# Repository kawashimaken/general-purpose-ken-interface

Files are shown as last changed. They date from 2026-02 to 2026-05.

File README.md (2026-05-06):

# KEN Interface

A modular, multi-MCU prototyping platform with a unified pin-assignment standard and horizontally-stackable expansion boards.

> **Status**: Hardware design (KiCad) is published in this repository. Software libraries (Hardware Abstraction Layer and demo applications) are **under active development** and will be released separately in the near future.

---

## 📺 Watch the Introduction

KEN Interface — The AI Voice Chatbot You Can Build with ESP32-S3 (https://www.youtube.com/watch?v=sNuc83q-v-A)

KEN Interface — Stop Stacking Your Dev Boards — There's a Better Way (https://www.youtube.com/watch?v=DMRa_tTHA18)

---

## What is KEN Interface?

At its core, **KEN Interface is a standardized pin-assignment pattern shared between MCU boards and expansion boards.**

If you have worked with Arduino shields, the idea will feel familiar — because the pin layout is fixed, any compatible expansion board just plugs straight in and works. KEN Interface follows the same philosophy, but with a few key differences.

### Three Distinctive Features

#### 1. Horizontal Expansion

Instead of stacking boards vertically like Arduino shields, KEN Interface uses **15×2 right-angle pin headers** so boards connect **side by side**. The left and right connectors are completely symmetrical — it does not matter which side you plug into.

Add a **junction board** into the mix, and you can expand in multiple directions: left, right, up, down. Since nothing is buried under another board, every module stays visible, and you can read the pin labels right off the PCB. No more hunting for which wire goes where.

#### 2. Multi-MCU Support

KEN Interface currently supports **four MCUs**:

| MCU | Notes |
|---|---|
| **ESP32** (WROOM-32) | Wi-Fi / BLE built-in |
| **ESP32-S3** (WROOM-1) | Wi-Fi / BLE / native USB / dual core |
| **Raspberry Pi Pico** (RP2040) | Dual core, PIO for I2S, low cost |
| **STM32G431** (WeAct CBU6) | 170 MHz, real DSP, hardware FPU |

The same expansion board works with all of them. **Swap the MCU board, and you are good to go — no rewiring required.**

#### 3. Software Portability

Even though each MCU uses different physical pin numbers, the **functional pin groups sit at fixed positions** across all KEN Interface boards. Build your code around a HAL (Hardware Abstraction Layer), and a single codebase can run on all four MCUs.

> The Ken Interface software library that provides this HAL is currently being developed and will be released in a separate repository.

---

## Pin Assignment Design

The pin layout exposes the default peripheral interfaces that most modern MCUs provide out of the box.

### Functional Pin Groups

| Group | Purpose |
|---|---|
| **UART_A** | General-purpose serial communication |
| **UART_B** | Secondary serial / debugging (some MCUs have native USB instead) |
| **I2C** | Sensors, OLEDs, character LCDs, I/O expanders |
| **SPI** | TFT displays, fast peripherals |
| **I2S_A / I2S_B** | Microphones, digital audio (PIO emulation on Pico) |
| **PWM_A — PWM_F** | DC motors, stepper motors, BLDC motors, servos |
| **ADC_A / ADC_B** | Analog inputs (sensors, joysticks) |
| **Power rails** | 3.3 V and 5 V |

### Design Principle

> *"If the MCU supports it, we connect it. If it does not, it is just **Not Available**."*

Not every MCU covers every group. For example:
- ESP32 (WROOM-32) does not expose UART_B (limited free GPIO).
- STM32G431 shares some SPI and PWM pins due to peripheral multiplexing constraints.

These were deliberate trade-offs, figured out the hard way through multiple board revisions.

### Detailed Pin Mapping

The complete pin assignment matrix across all four MCUs is documented in the KiCad schematic and accompanying spreadsheet (see [`kicad/`](./kicad/)).

---

## What Is in This Repository

```
.
├── kicad/              KiCad PCB project — schematic, board, and gerbers
├── LICENSE             MIT License
└── README.md           This file
```

Currently this repository contains the **hardware design only** (KiCad project for the KEN Interface base board and expansion modules).

The accompanying software (HAL library and example applications) is under active development and will be linked here once published.

---

## Hardware

### Connector Specification

- **Side connectors**: 15×2 right-angle pin headers, 2.54 mm pitch
- **Symmetric pinout**: left and right sides are mirror images, so any expansion board can attach to either side
- **Power**: 3.3 V and 5 V rails routed through every connector

### Expansion Boards (existing designs)

Several expansion modules built on KEN Interface:

- **SPI TFT display board** (ILI9341, 2.4-inch)
- **I2S microphone + audio amplifier board**
- **MCP23008 I/O expander + analog joystick board**
- **BLDC motor driver board** (3-PWM, for SmartKnob / SimpleFOC)
- **Junction board** (4-direction expansion)

---

## Challenges and Limitations

KEN Interface is not a silver bullet. A few honest caveats:

- **Manufacturing cost.** Symmetric routing tends to push designs toward 4-layer PCBs, making mistakes expensive.
- **Board footprint.** Horizontal expansion uses desk space. KEN Interface is designed for **prototyping and experimentation**, not for final compact products. Once a design is validated, the natural next step is to consolidate everything onto a single custom PCB.
- **Software portability has limits.** A few examples:
  - LovyanGFX does not support STM32G4.
  - STM32G431 often requires SoftWire instead of hardware I2C in this pin layout.
  - Dual-core parallelism is specific to ESP32 / ESP32-S3.
  - I2S microphone support on STM32G431 lacks a ready-made Arduino library.

A well-designed HAL can hide many of these differences, but it cannot eliminate them entirely. KEN Interface provides a common hardware standard and a foundation for HAL design — it does not remove the underlying differences between MCUs.

- **Not for every use case.** Highly specialized projects (large multi-display setups, tightly integrated mechanical builds) may still need fully custom PCBs.

---

## Roadmap

Planned additions include:

- LoRa expansion board
- CAN bus expansion board
- Ethernet expansion board
- Additional sensor modules
- Support for more MCUs
- Dedicated power supply board
- Software HAL library and reference applications (separate repository, coming soon)

---

## Build Your Own

The KiCad project template is published in this repository. If you would like to build your own KEN Interface-compatible board, the schematic symbols, footprints, and design rules are all in [`kicad/`](./kicad/).

Pull requests, design suggestions, and new expansion-board ideas are very welcome.

---

## License

The hardware design files in this repository are released under the **MIT License** (see [LICENSE](./LICENSE)).

Future software components will be released under their own licenses — typically MIT or LGPL — and will be linked from this README once published.

---

## Author

Designed and maintained by **Kawashima Ken** ([@kawashimaken](https://github.com/kawashimaken)).

If you build something with KEN Interface, please consider sharing it — issues, pull requests, and ideas are all welcome.

---

## Acknowledgments

- KEN Interface stands on the shoulders of the wider open-source hardware community: KiCad, Arduino, ESP-IDF, Earle Philhower's Arduino-Pico core, Arduino_Core_STM32, and many display / sensor library authors whose work makes prototyping like this possible.

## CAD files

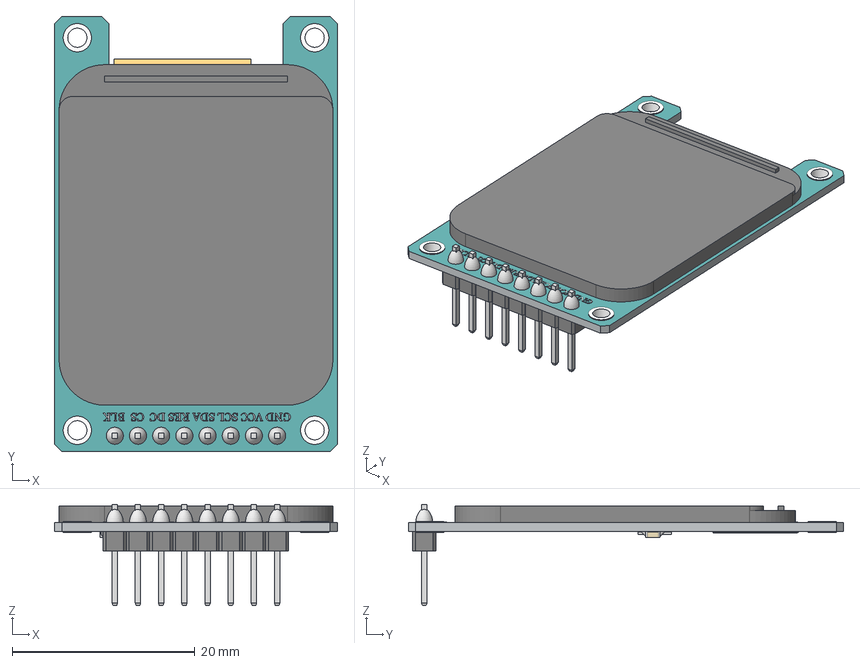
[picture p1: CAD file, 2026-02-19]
kicad/display-with-ken-interface-2/3d_models/Display 1.69 ST7789V2.stp
31.0 x 47.7 x 11.1 mm
PCB
Display
Pin x 8
R-0603 x 3
C-0603 x 2
U-0603

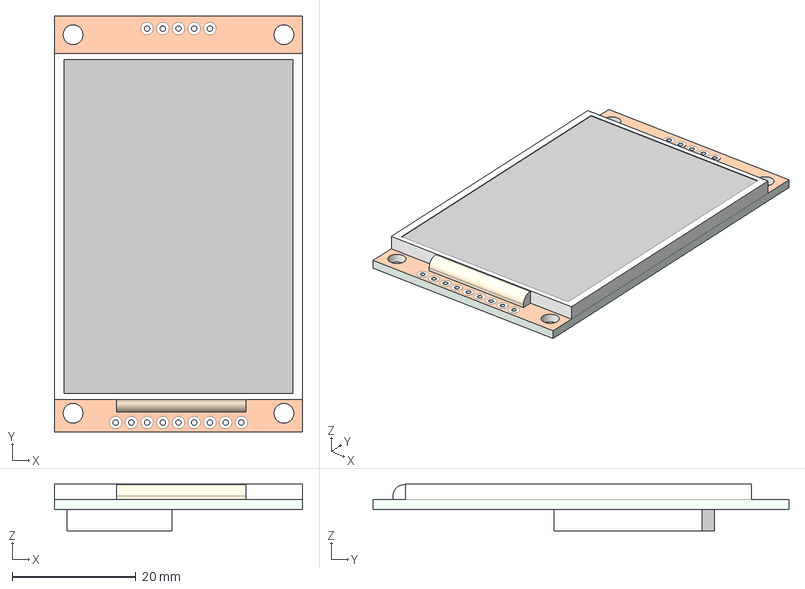
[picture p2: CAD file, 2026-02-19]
kicad/display-with-ken-interface-2/3d_models/2.2 inch tft display .step
40.1 x 67.2 x 7.57 mm

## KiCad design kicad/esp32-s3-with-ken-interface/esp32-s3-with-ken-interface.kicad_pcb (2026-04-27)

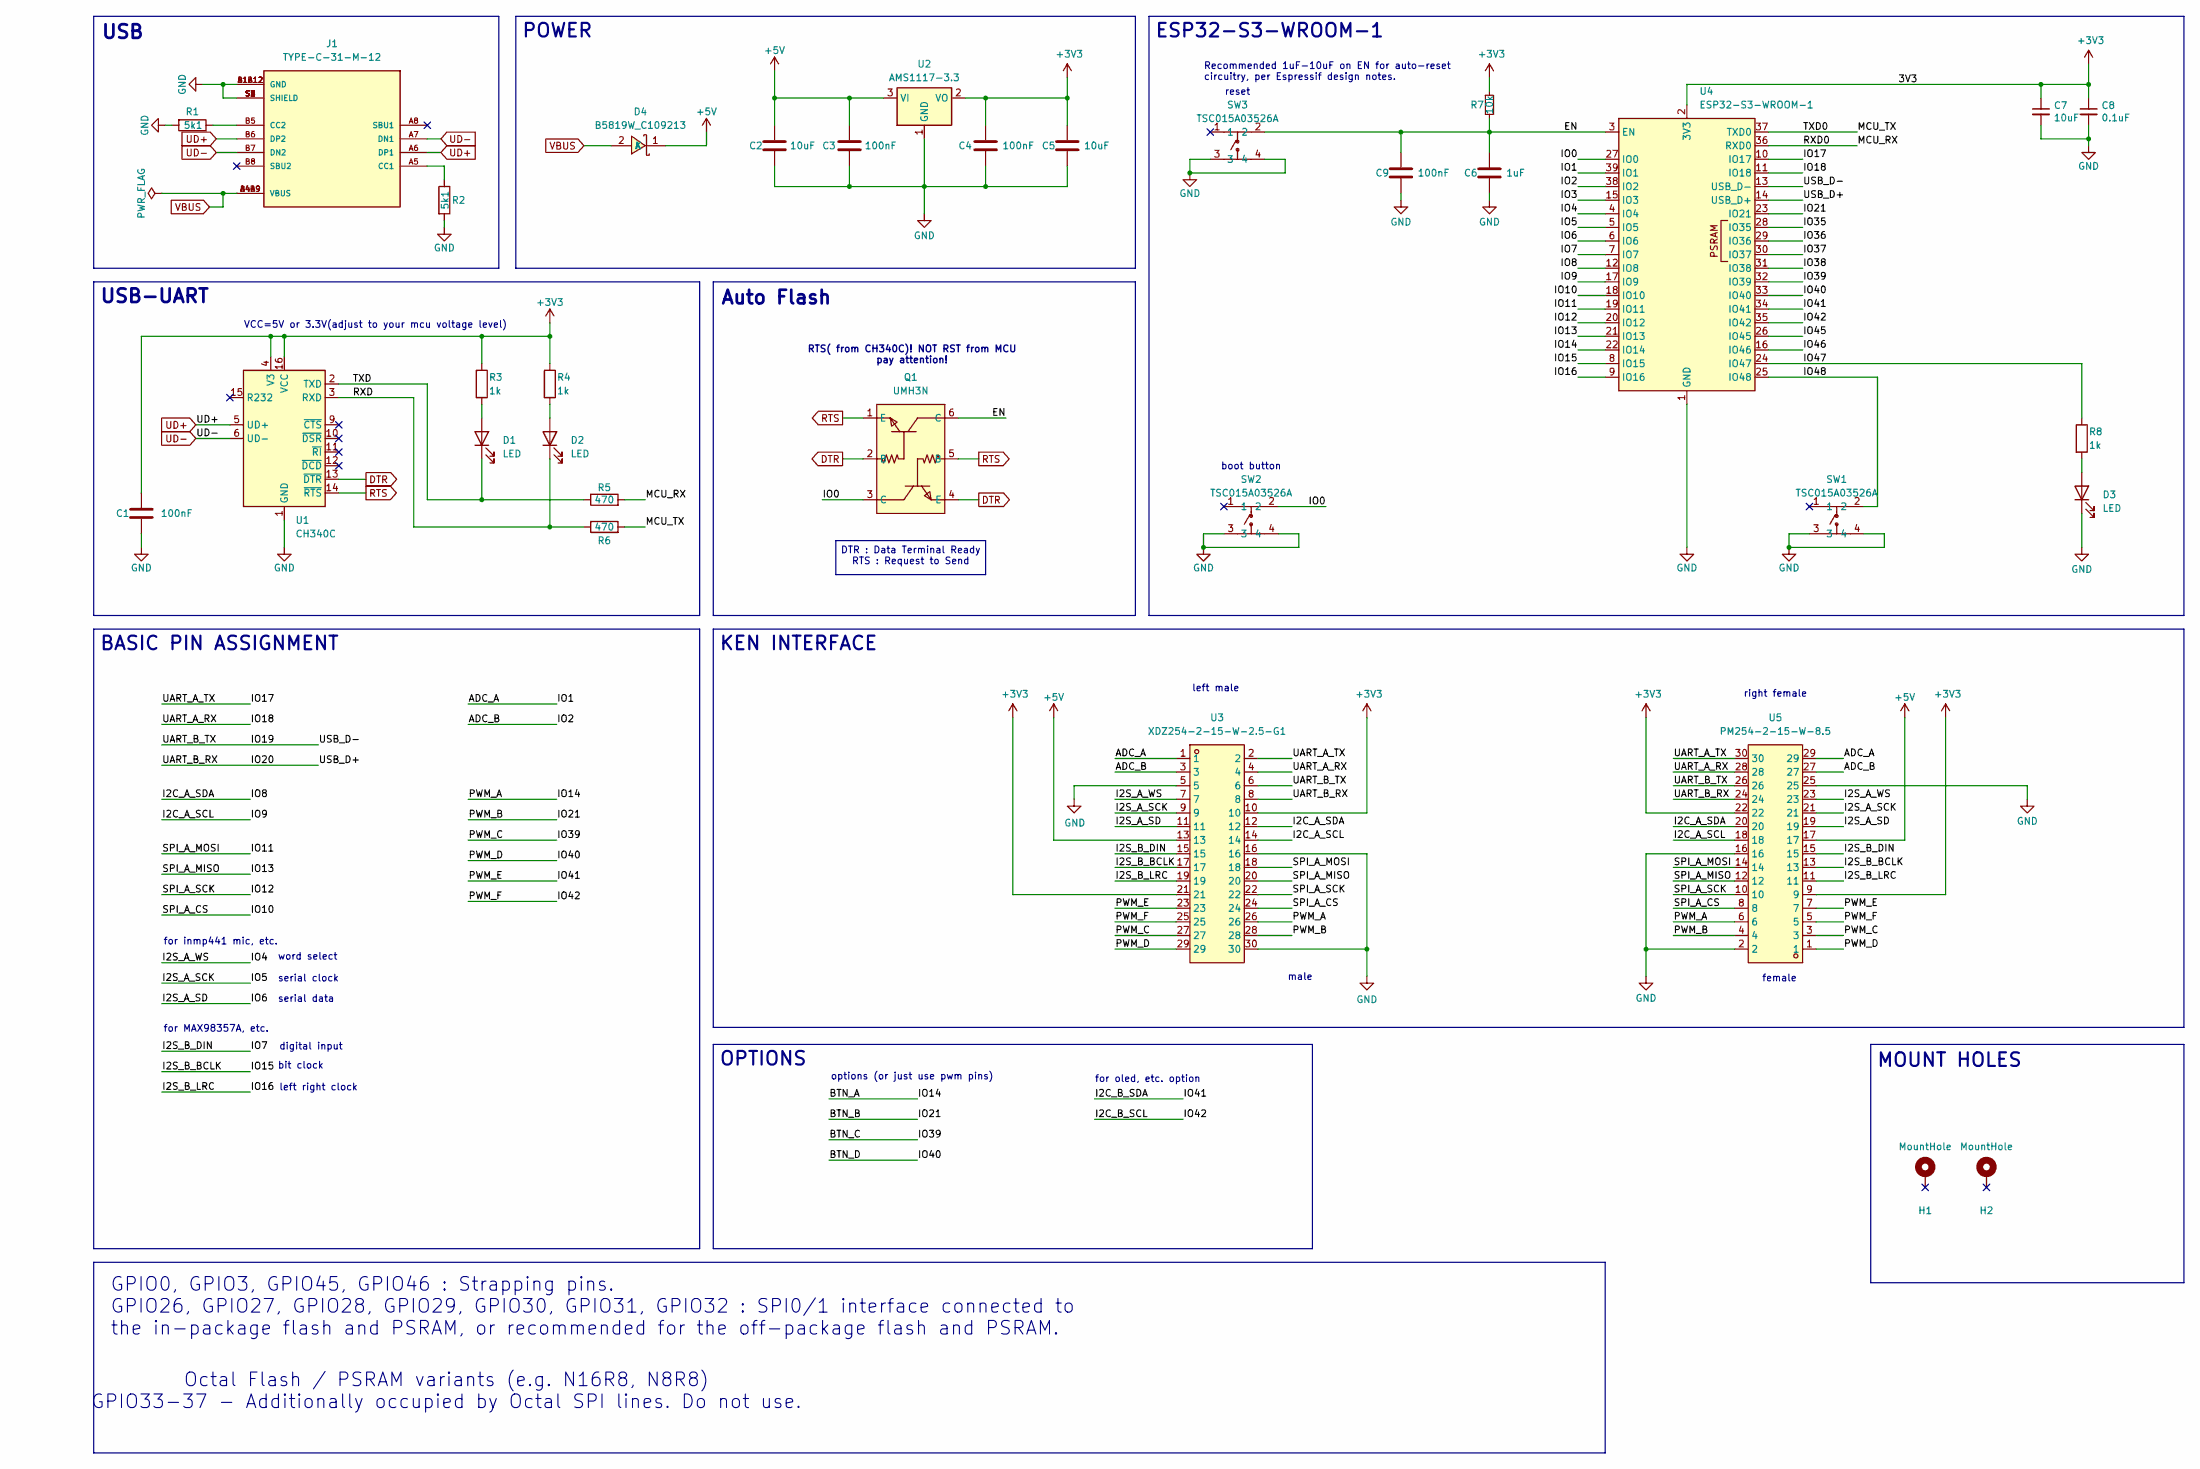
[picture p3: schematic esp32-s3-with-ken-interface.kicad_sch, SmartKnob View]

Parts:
C1, C3, C4, C9: 100nF; C_0603_1608Metric_Pad1.08x0.95mm_HandSolder
C2, C5: 10uF; C_1206_3216Metric_Pad1.33x1.80mm_HandSolder
C6: 1uF; C_0603_1608Metric_Pad1.08x0.95mm_HandSolder
C7: 10uF; C_0805_2012Metric_Pad1.18x1.45mm_HandSolder; LCSC C15850
C8: 0.1uF; C_0603_1608Metric_Pad1.08x0.95mm_HandSolder; LCSC C1591
D1, D2, D3: LED; LED_1206_3216Metric_Pad1.42x1.75mm_HandSolder
D4: B5819W_C109213; SOD-123_L2.8-W1.8-LS3.7-RD; LCSC Part C109213
H1, H2: MountHole; MountingHole_3.2mm_M3_DIN965_Pad; LCSC C2911210 or C2911532 (screw), C2961595 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
J1: TYPE-C-31-M-12; HRO_TYPE-C-31-M-12; PARTREV A
Q1: UMH3N; SC-70-6_L2.2-W1.3-P0.65-LS2.1-BR; LCSC Part C62892
R1, R2: 5k1; R_0603_1608Metric_Pad0.98x0.95mm_HandSolder
R3, R4, R8: 1k; R_0603_1608Metric_Pad0.98x0.95mm_HandSolder
R5, R6: 470; R_0603_1608Metric_Pad0.98x0.95mm_HandSolder
R7: 10k; R_0603_1608Metric_Pad0.98x0.95mm_HandSolder; LCSC C98220
SW1, SW2, SW3: TSC015A03526A; SW-SMD_4P-L4.5-W4.5-P3.00-LS6.8; LCSC Part C2888900
U1: CH340C; SOIC-16_3.9x9.9mm_P1.27mm
U2: AMS1117-3.3; SOT-223-3_TabPin2
U3: XDZ254-2-15-W-2.5-G1; HDR-TH_30P-P2.54-H-M-R2-C15-S2.54-N; LCSC Part C18905913
U4: ESP32-S3-WROOM-1
U5: PM254-2-15-W-8.5; HDR-TH_30P-P2.54-H-F-R2-C15-W8.5; LCSC Part C2897435

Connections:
+3V3: C1.1, C4.1, C5.1, C7.1, C8.1, R3.1, R4.1, R7.1, U1.4 (V3), U1.16 (VCC), U2.2 (VO), U3.10, U3.21, U4.2 (3V3), U5.9, U5.22
+5V: C2.1, C3.1, D4.1 (K), U2.3 (VI), U3.13, U5.17
/ADC_A: U3.1, U4.39 (IO1), U5.29
/ADC_B: U3.3, U4.38 (IO2), U5.27
/BTN_A: U3.26, U4.22 (IO14), U5.6
/BTN_B: U3.28, U4.23 (IO21), U5.4
/BTN_C: U3.27, U4.32 (IO39), U5.3
/BTN_D: U3.29, U4.33 (IO40), U5.1
/EN: C6.1, C9.1, Q1.6 (C), R7.2, SW3.2, U4.3 (EN)
/I2C_A_SCL: U3.14, U4.17 (IO9), U5.18
/I2C_A_SDA: U3.12, U4.12 (IO8), U5.20
/I2C_B_SCL: U3.25, U4.35 (IO42), U5.5
/I2C_B_SDA: U3.23, U4.34 (IO41), U5.7
/I2S_A_SCK: U3.9, U4.5 (IO5), U5.21
/I2S_A_SD: U3.11, U4.6 (IO6), U5.19
/I2S_A_WS: U3.7, U4.4 (IO4), U5.23
/I2S_B_BCLK: U3.17, U4.8 (IO15), U5.13
/I2S_B_DIN: U3.15, U4.7 (IO7), U5.15
/I2S_B_LRC: U3.19, U4.9 (IO16), U5.11
/IO0: Q1.3 (C), SW2.2, U4.27 (IO0)
/IO3: U4.15 (IO3)
/IO10: U3.24, U4.18 (IO10), U5.8
/IO11: U3.18, U4.19 (IO11), U5.14
/IO12: U3.22, U4.20 (IO12), U5.10
/IO13: U3.20, U4.21 (IO13), U5.12
/IO17: U3.2, U4.10 (IO17), U5.30
/IO18: U3.4, U4.11 (IO18), U5.28
/IO19: U3.6, U4.13 (USB_D-), U5.26
/IO20: U3.8, U4.14 (USB_D+), U5.24
/IO35: U4.28 (IO35)
/IO36: U4.29 (IO36)
/IO37: U4.30 (IO37)
/IO38: U4.31 (IO38)
/IO45: U4.26 (IO45)
/IO46: U4.16 (IO46)
/IO47: R8.1, U4.24 (IO47)
/IO48: SW1.2, U4.25 (IO48)
/MCU_RX: R5.2, U4.36 (RXD0)
/MCU_TX: R6.2, U4.37 (TXD0)
/RXD: D2.1 (K), R6.1, U1.3 (RXD)
/TXD: D1.1 (K), R5.1, U1.2 (TXD)
DTR: Q1.2 (B), Q1.4 (E), U1.13 (~DTR)
GND: C1.2, C2.2, C3.2, C4.2, C5.2, C6.2, C7.2, C8.2, C9.2, D3.1 (K), J1.A1B12 (GND), J1.B1A12 (GND), J1.S1 (SHIELD), J1.S2 (SHIELD), J1.S3 (SHIELD), J1.S4 (SHIELD), R1.2, R2.2, SW1.3, SW1.4, SW2.3, SW2.4, SW3.3, SW3.4, U1.1 (GND), U2.1 (GND), U3.5, U3.16, U3.30, U4.1 (GND), U4.40 (GND), U4.41 (GND), U5.2, U5.16, U5.25
unnamed: D1.2 (A), R3.2
unnamed: D2.2 (A), R4.2
unnamed: D3.2 (A), R8.2
unnamed: J1.A5 (CC1), R2.1
unnamed: J1.B5 (CC2), R1.1
RTS: Q1.1 (E), Q1.5 (B), U1.14 (~RTS)
UD+: J1.A6 (DP1), J1.B6 (DP2), U1.5 (UD+)
UD-: J1.A7 (DN1), J1.B7 (DN2), U1.6 (UD-)
VBUS: D4.2 (A), J1.A4B9 (VBUS), J1.B4A9 (VBUS)

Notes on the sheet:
POWER
VCC=5V or 3.3V(adjust to your mcu voltage level)
for MAX98357A, etc.
USB
KEN INTERFACE
GPIO0, GPIO3, GPIO45, GPIO46 : Strapping pins. GPIO26, GPIO27, GPIO28, GPIO29, GPIO30, GPIO31, GPIO32 : SPI0/1 interface connected to the in-package flash and PSRAM, or recommended for the off-package flash and PSRAM.
MOUNT HOLES
right female
RTS( from CH340C)! NOT RST from MCU pay attention!
female
word select
BASIC PIN ASSIGNMENT
male
serial clock
left right clock
Octal Flash / PSRAM variants (e.g. N16R8, N8R8) GPIO33-37 - Additionally occupied by Octal SPI lines. Do not use.
bit clock
left male
ESP32-S3-WROOM-1
OPTIONS
Recommended 1uF-10uF on EN for auto-reset circuitry, per Espressif design notes.
USB-UART
boot button
reset
options (or just use pwm pins)
digital input
serial data
for oled, etc. option
for inmp441 mic, etc.
Auto Flash
DTR : Data Terminal Ready RTS : Request to Send

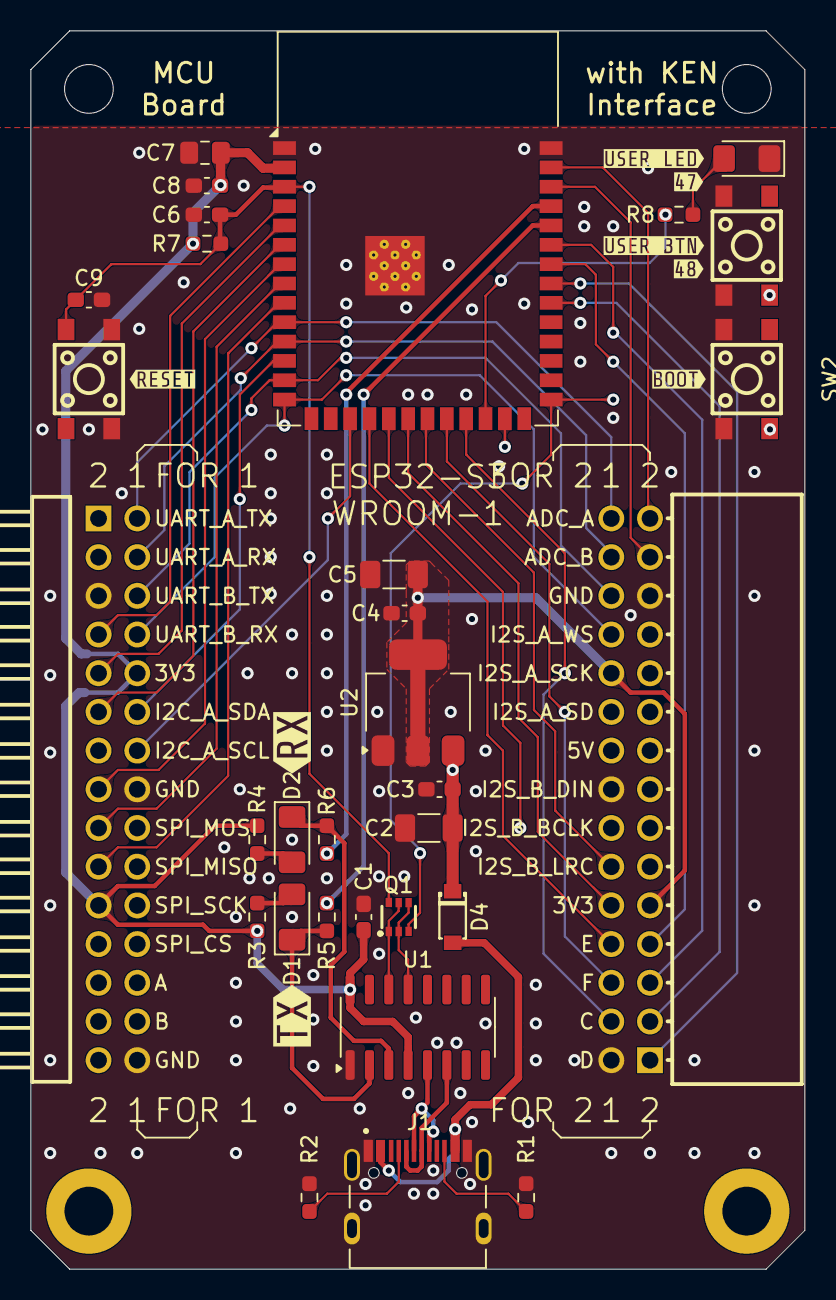
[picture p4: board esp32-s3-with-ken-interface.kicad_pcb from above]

Board: 4 copper layers, 50.8 x 81.3 mm, 41 parts (0 on the bottom side), 45 nets.

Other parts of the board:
kibuzzard-69BBE7EF: G***; kibuzzard-69BBE7EF
kibuzzard-69BBE90D: G***; kibuzzard-69BBE90D
kibuzzard-69BBF8B2: G***; kibuzzard-69BBF8B2
kibuzzard-69BBF8C4: G***; kibuzzard-69BBF8C4
kibuzzard-69BBF8DF: G***; kibuzzard-69BBF8DF
kibuzzard-696F5E7C: G***; kibuzzard-696F5E7C
kibuzzard-696F5E93: G***; kibuzzard-696F5E93
kibuzzard-69756FE8: G***; kibuzzard-69756FE8

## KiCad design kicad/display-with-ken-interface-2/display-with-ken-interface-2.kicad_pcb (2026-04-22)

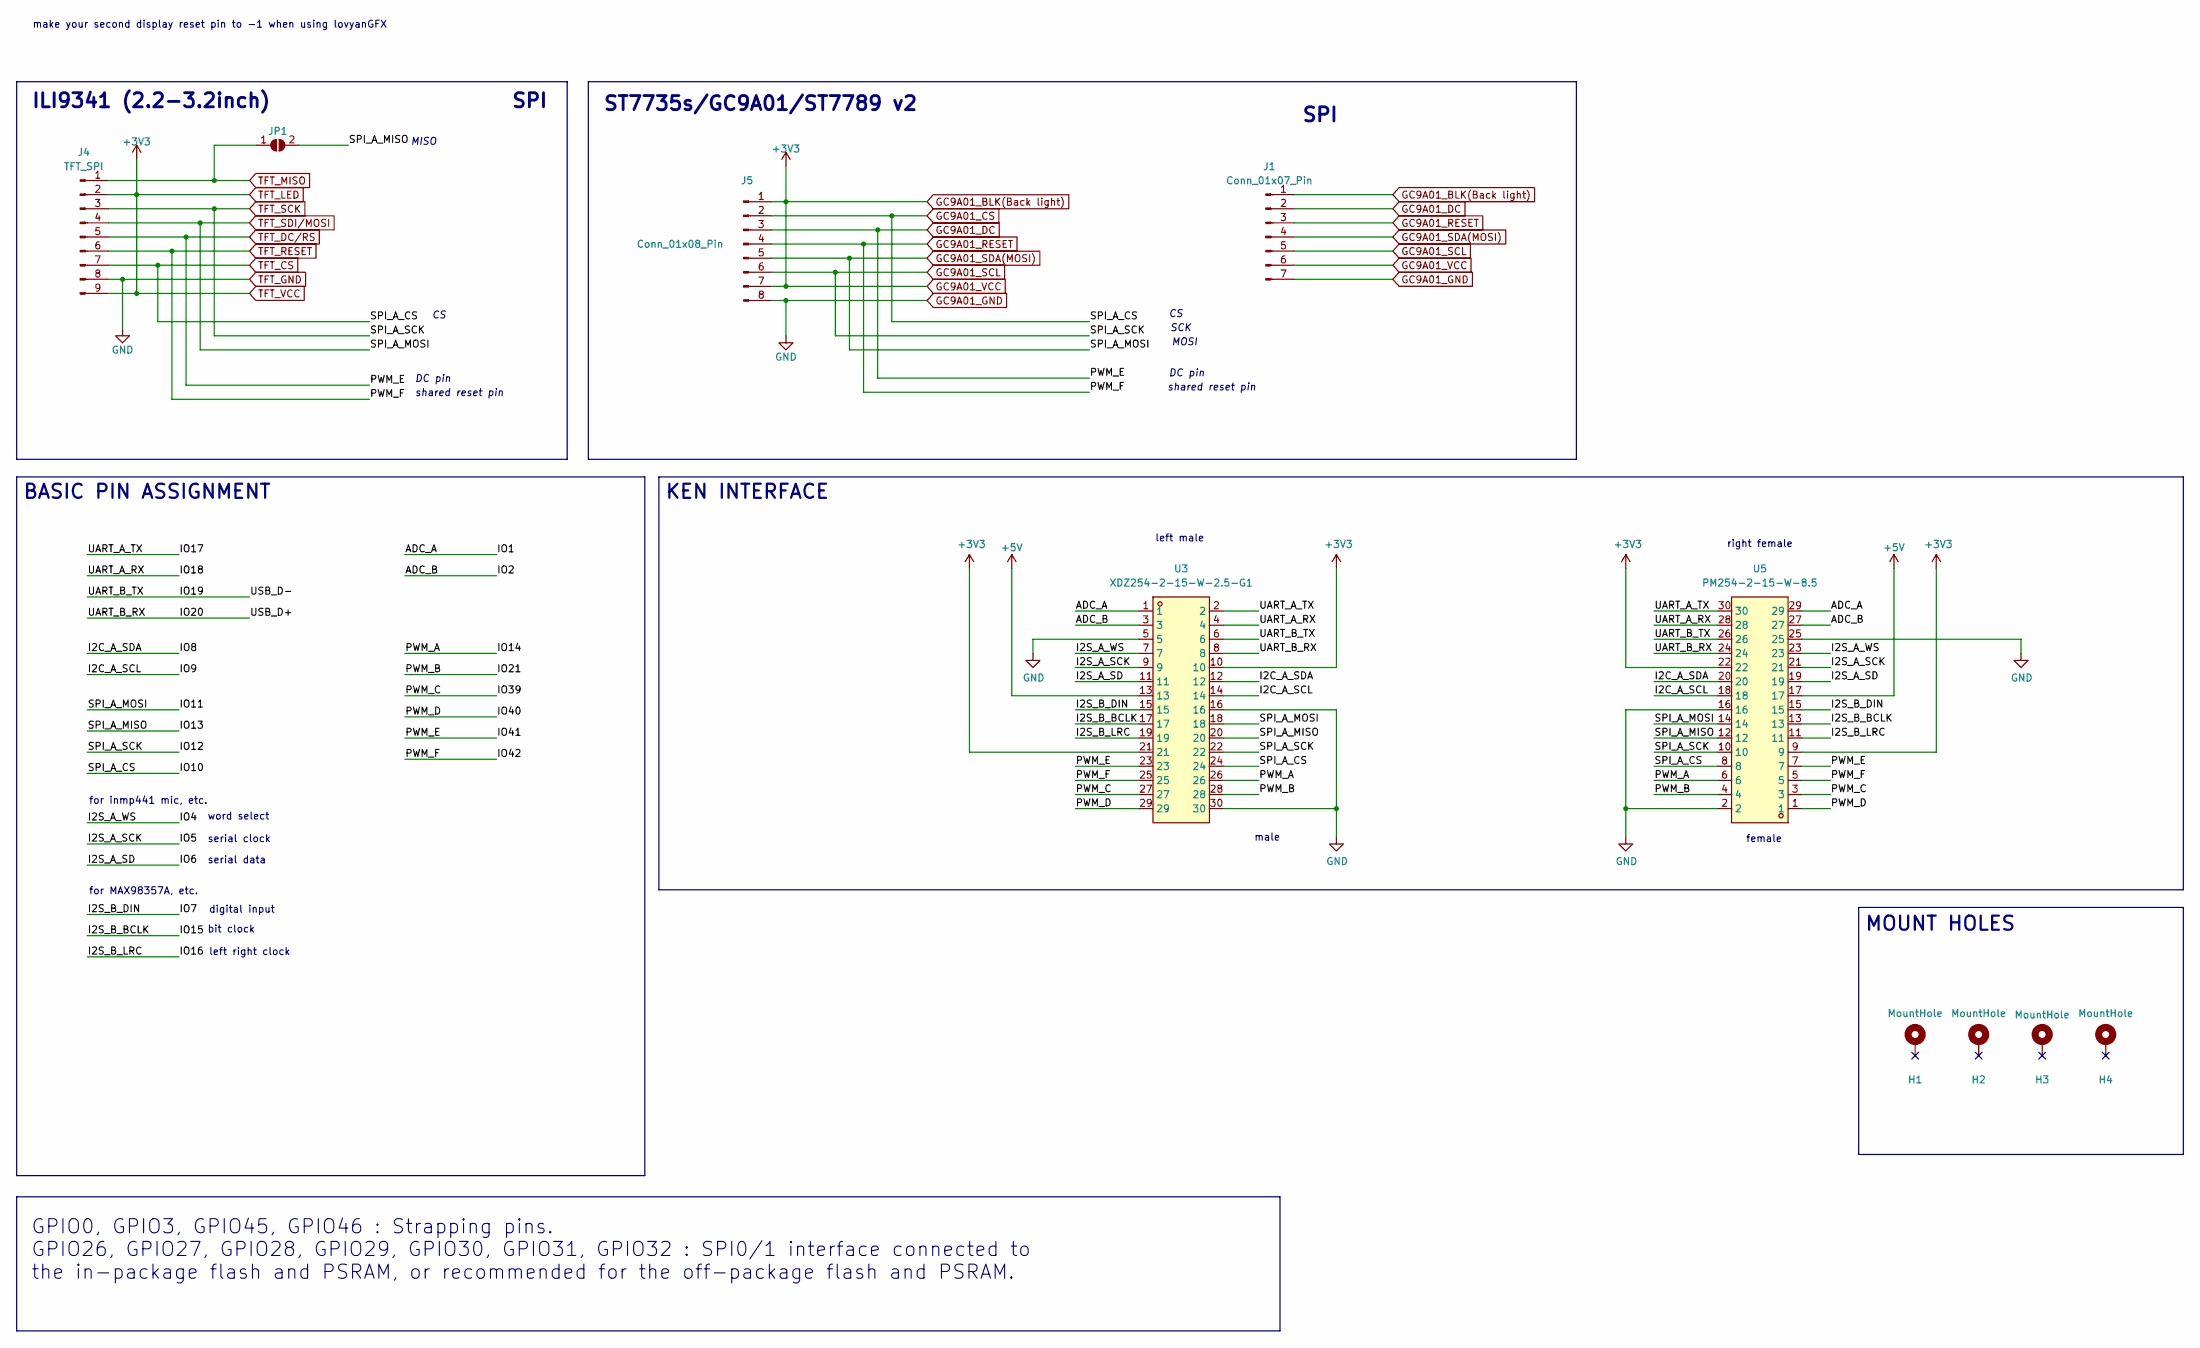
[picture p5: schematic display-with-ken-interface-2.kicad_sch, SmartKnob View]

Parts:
H1, H2, H3, H4: MountHole; MountingHole_3.2mm_M3_DIN965_Pad; LCSC C2911210 or C2911532 (screw), C2961595 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
J1: Conn_01x07_Pin; PinHeader_1x07_P2.54mm_Vertical
J4: TFT_SPI; PinHeader_1x09_P2.54mm_Vertical
J5: Conn_01x08_Pin; PinHeader_1x08_P2.54mm_Vertical
JP1: SolderJumper_2_Open; SolderJumper-2_P1.3mm_Open_RoundedPad1.0x1.5mm
U3: XDZ254-2-15-W-2.5-G1; HDR-TH_30P-P2.54-H-M-R2-C15-S2.54-N; LCSC Part C18905913
U5: PM254-2-15-W-8.5; HDR-TH_30P-P2.54-H-F-R2-C15-W8.5; LCSC Part C2897435

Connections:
+5V: U3.13, U5.17
/ADC_A: U3.1, U5.29
/ADC_B: U3.3, U5.27
/I2C_A_SCL: U3.14, U5.18
/I2C_A_SDA: U3.12, U5.20
/I2S_A_SCK: U3.9, U5.21
/I2S_A_SD: U3.11, U5.19
/I2S_A_WS: U3.7, U5.23
/I2S_B_BCLK: U3.17, U5.13
/I2S_B_DIN: U3.15, U5.15
/I2S_B_LRC: U3.19, U5.11
/IO13: JP1.2 (B), U3.20, U5.12
/IO14: U3.26, U5.6
/IO17: U3.2, U5.30
/IO18: U3.4, U5.28
/IO19: U3.6, U5.26
/IO20: U3.8, U5.24
/IO21: U3.28, U5.4
/IO39: U3.27, U5.3
/IO40: U3.29, U5.1
GC9A01_BLK(Back light): J1.1, J1.6, J4.2, J4.9, J5.1, J5.7, U3.10, U3.21, U5.9, U5.22
GC9A01_CS: J4.7, J5.2, U3.24, U5.8
GC9A01_DC: J1.2, J4.5, J5.3, U3.23, U5.7
GC9A01_GND: J1.7, J4.8, J5.8, U3.5, U3.16, U3.30, U5.2, U5.16, U5.25
GC9A01_RESET: J1.3, J4.6, J5.4, U3.25, U5.5
GC9A01_SCL: J1.5, J4.3, J5.6, U3.22, U5.10
GC9A01_SDA(MOSI): J1.4, J4.4, J5.5, U3.18, U5.14
TFT_MISO: J4.1, JP1.1 (A)

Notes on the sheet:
shared reset pin
for MAX98357A, etc.
KEN INTERFACE
GPIO0, GPIO3, GPIO45, GPIO46 : Strapping pins. GPIO26, GPIO27, GPIO28, GPIO29, GPIO30, GPIO31, GPIO32 : SPI0/1 interface connected to the in-package flash and PSRAM, or recommended for the off-package flash and PSRAM.
SCK
SPI
MOUNT HOLES
right female
female
DC pin
word select
MISO
BASIC PIN ASSIGNMENT
male
serial clock
left right clock
bit clock
MOSI
left male
ST7735s/GC9A01/ST7789 v2
ILI9341 (2.2-3.2inch)
digital input
serial data
make your second display reset pin to -1 when using lovyanGFX
for inmp441 mic, etc.

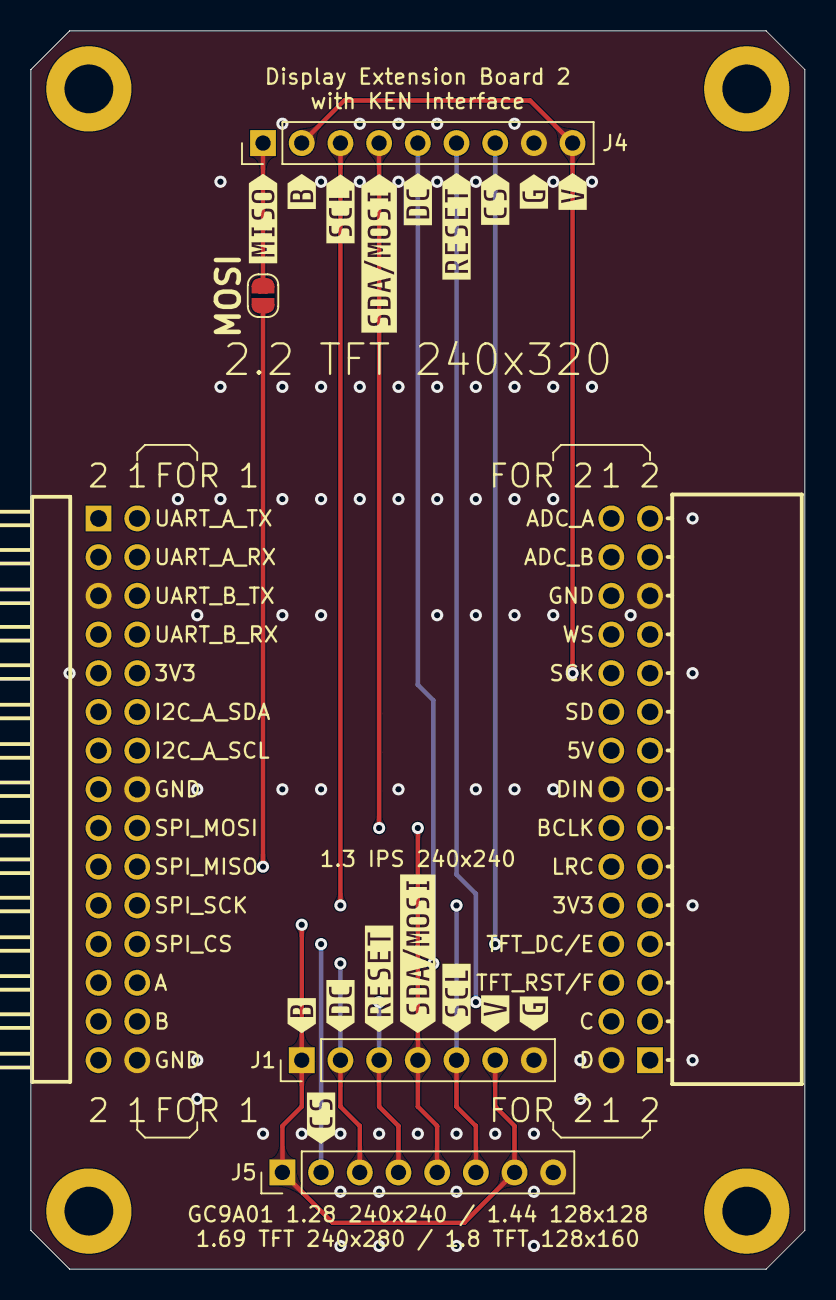
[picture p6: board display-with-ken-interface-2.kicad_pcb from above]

Board: 4 copper layers, 50.8 x 81.3 mm, 27 parts (0 on the bottom side), 28 nets.

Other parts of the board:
kibuzzard-69E872B6: G***; kibuzzard-69E872B6
kibuzzard-69E872D5: G***; kibuzzard-69E872D5
kibuzzard-69E874A0: G***; kibuzzard-69E874A0
kibuzzard-69E874A4: G***; kibuzzard-69E874A4
kibuzzard-69E874AD: G***; kibuzzard-69E874AD
kibuzzard-69E874B2: G***; kibuzzard-69E874B2
kibuzzard-69E8720F: G***; kibuzzard-69E8720F
kibuzzard-69E8724B: G***; kibuzzard-69E8724B
kibuzzard-69E8725D: G***; kibuzzard-69E8725D
kibuzzard-69E8747C: G***; kibuzzard-69E8747C
kibuzzard-69E8749A: G***; kibuzzard-69E8749A
kibuzzard-69E87221: G***; kibuzzard-69E87221
kibuzzard-69E87232: G***; kibuzzard-69E87232
kibuzzard-69E87269: G***; kibuzzard-69E87269
kibuzzard-69E87476: G***; kibuzzard-69E87476
kibuzzard-69E87482: G***; kibuzzard-69E87482
kibuzzard-69E87487: G***; kibuzzard-69E87487

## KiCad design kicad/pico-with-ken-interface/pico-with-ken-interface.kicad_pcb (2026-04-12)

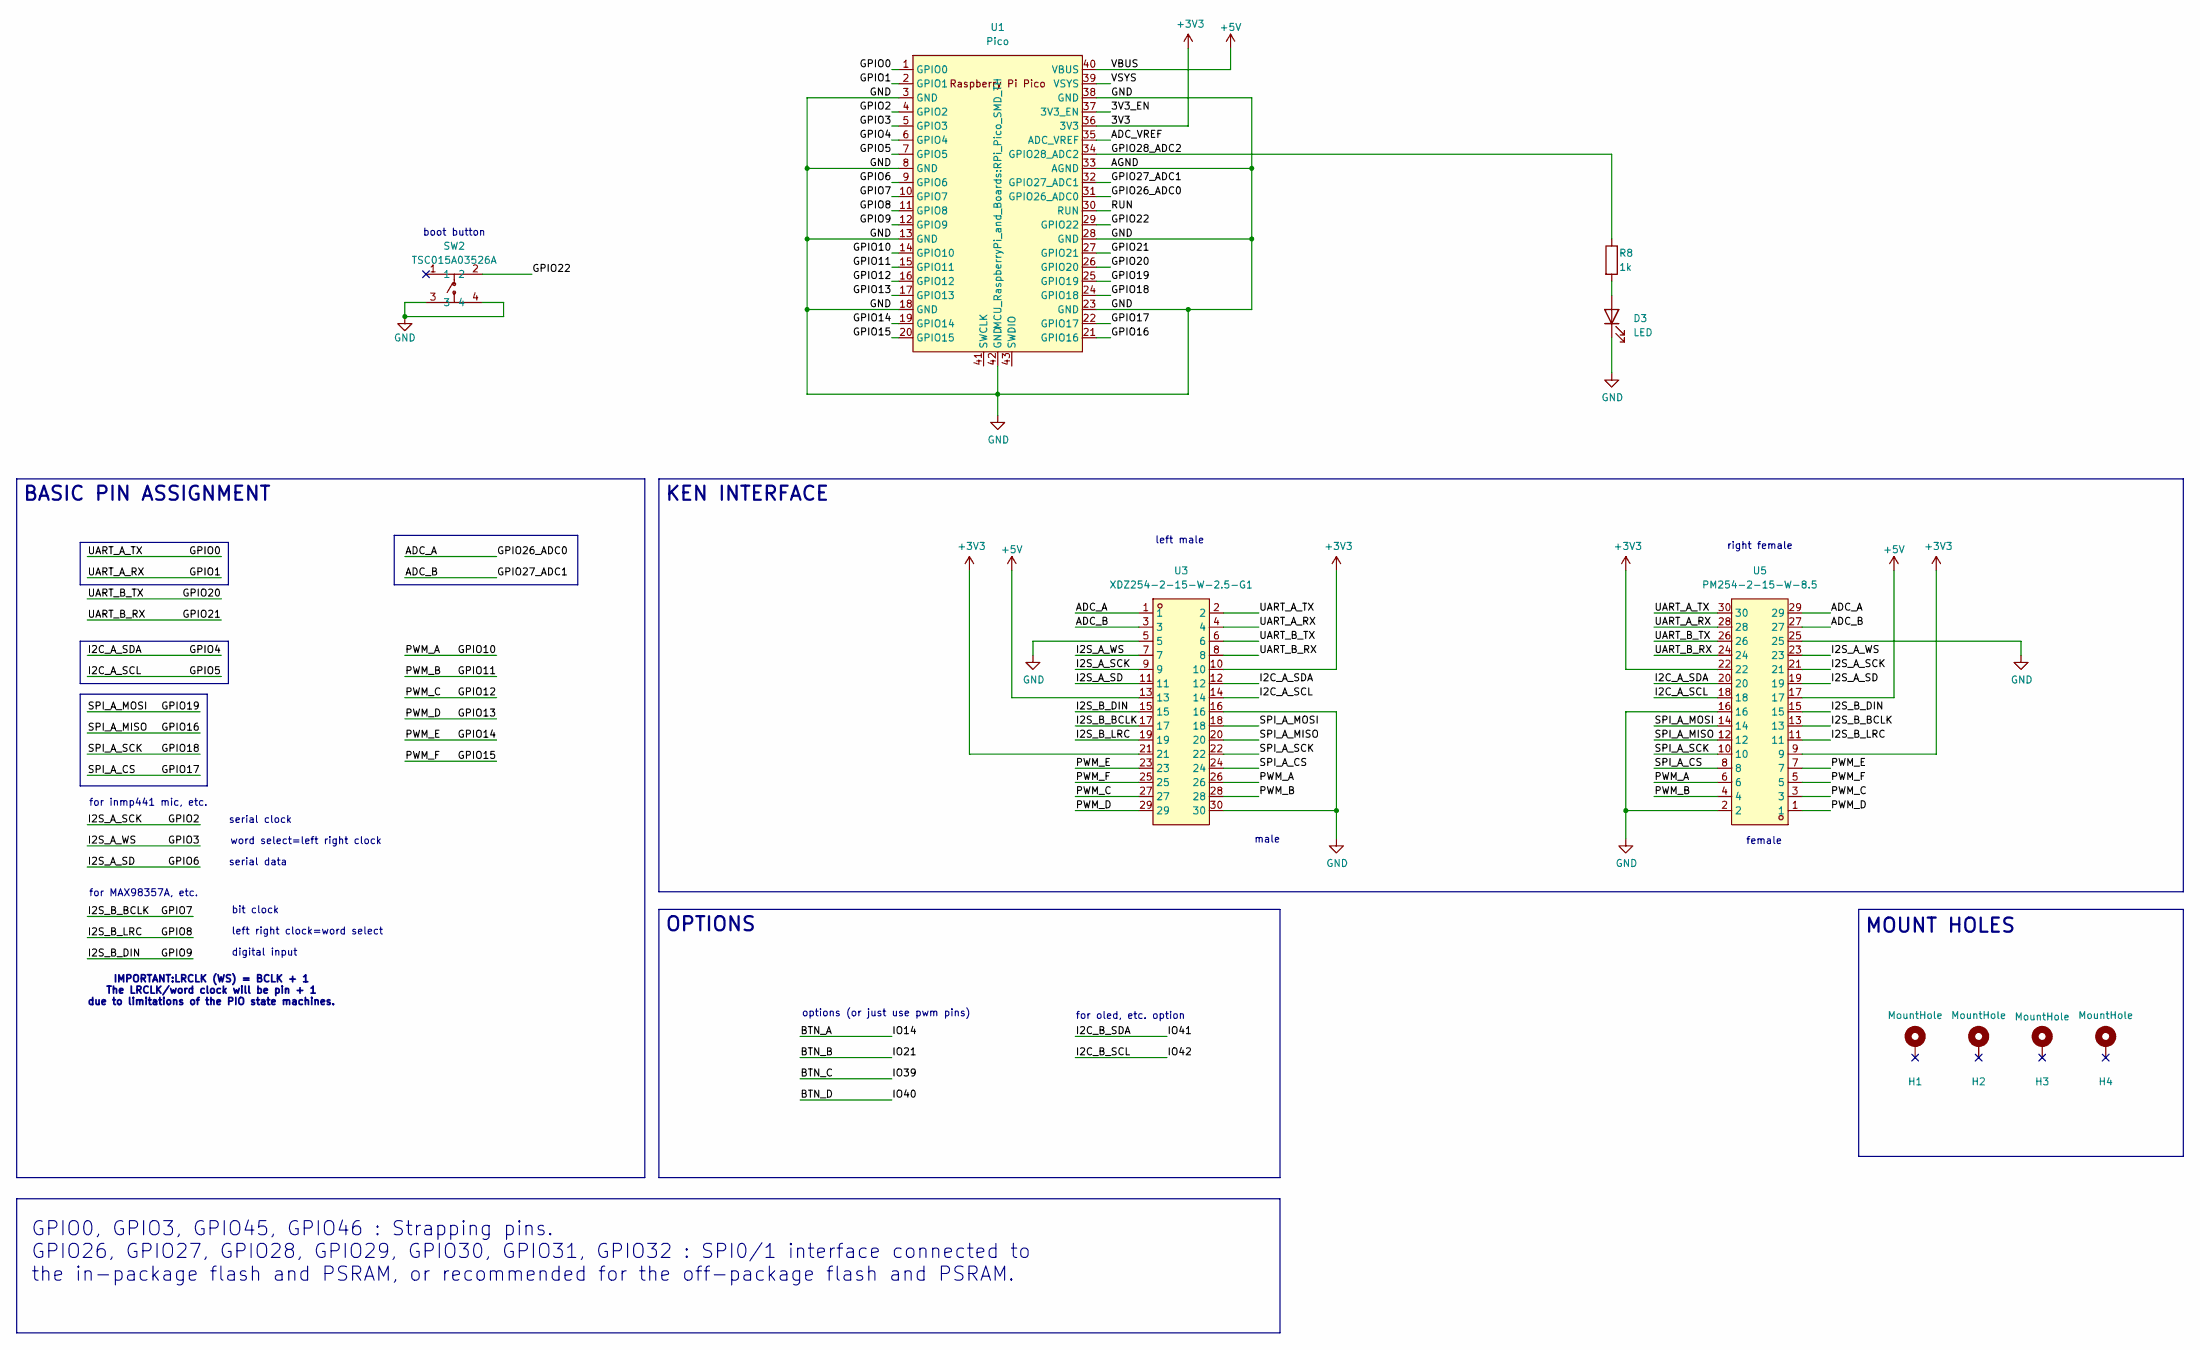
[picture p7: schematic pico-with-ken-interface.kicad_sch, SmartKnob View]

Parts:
D3: LED; LED_1206_3216Metric_Pad1.42x1.75mm_HandSolder
H1, H2, H3, H4: MountHole; MountingHole_3.2mm_M3_DIN965_Pad; LCSC C2911210 or C2911532 (screw), C2961595 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
R8: 1k; R_0603_1608Metric_Pad0.98x0.95mm_HandSolder
SW2: TSC015A03526A; SW-SMD_4P-L4.5-W4.5-P3.00-LS6.8; LCSC Part C2888900
U1: Pico; RPi_Pico_SMD_TH
U3: XDZ254-2-15-W-2.5-G1; HDR-TH_30P-P2.54-H-M-R2-C15-S2.54-N; LCSC Part C18905913
U5: PM254-2-15-W-8.5; HDR-TH_30P-P2.54-H-F-R2-C15-W8.5; LCSC Part C2897435

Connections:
+3V3: U1.36 (3V3), U3.10, U3.21, U5.9, U5.22
+5V: U1.40 (VBUS), U3.13, U5.17
/3V3_EN: U1.37 (3V3_EN)
/ADC_A: U1.31 (GPIO26_ADC0), U3.1, U5.29
/ADC_B: U1.32 (GPIO27_ADC1), U3.3, U5.27
/ADC_VREF: U1.35 (ADC_VREF)
/GPIO0: U1.1 (GPIO0), U3.2, U5.30
/GPIO1: U1.2 (GPIO1), U3.4, U5.28
/GPIO2: U1.4 (GPIO2), U3.9, U5.21
/GPIO3: U1.5 (GPIO3), U3.7, U5.23
/GPIO4: U1.6 (GPIO4), U3.12, U5.20
/GPIO5: U1.7 (GPIO5), U3.14, U5.18
/GPIO6: U1.9 (GPIO6), U3.11, U5.19
/GPIO7: U1.10 (GPIO7), U3.17, U5.13
/GPIO8: U1.11 (GPIO8), U3.19, U5.11
/GPIO9: U1.12 (GPIO9), U3.15, U5.15
/GPIO10: U1.14 (GPIO10), U3.26, U5.6
/GPIO11: U1.15 (GPIO11), U3.28, U5.4
/GPIO12: U1.16 (GPIO12), U3.27, U5.3
/GPIO13: U1.17 (GPIO13), U3.29, U5.1
/GPIO14: U1.19 (GPIO14), U3.23, U5.7
/GPIO15: U1.20 (GPIO15), U3.25, U5.5
/GPIO16: U1.21 (GPIO16), U3.20, U5.12
/GPIO17: U1.22 (GPIO17), U3.24, U5.8
/GPIO18: U1.24 (GPIO18), U3.22, U5.10
/GPIO19: U1.25 (GPIO19), U3.18, U5.14
/GPIO20: U1.26 (GPIO20), U3.6, U5.26
/GPIO21: U1.27 (GPIO21), U3.8, U5.24
/GPIO22: SW2.2, U1.29 (GPIO22)
/GPIO28_ADC2: R8.1, U1.34 (GPIO28_ADC2)
/RUN: U1.30 (RUN)
/VSYS: U1.39 (VSYS)
GND: D3.1 (K), SW2.3, SW2.4, U1.3 (GND), U1.8 (GND), U1.13 (GND), U1.18 (GND), U1.23 (GND), U1.28 (GND), U1.33 (AGND), U1.38 (GND), U1.42 (GND), U3.5, U3.16, U3.30, U5.2, U5.16, U5.25
unnamed: D3.2 (A), R8.2

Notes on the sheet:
IMPORTANT:LRCLK (WS) = BCLK + 1 The LRCLK/word clock will be pin + 1 due to limitations of the PIO state machines.
for MAX98357A, etc.
KEN INTERFACE
GPIO0, GPIO3, GPIO45, GPIO46 : Strapping pins. GPIO26, GPIO27, GPIO28, GPIO29, GPIO30, GPIO31, GPIO32 : SPI0/1 interface connected to the in-package flash and PSRAM, or recommended for the off-package flash and PSRAM.
MOUNT HOLES
right female
female
word select=left right clock
BASIC PIN ASSIGNMENT
male
serial clock
left right clock=word select
bit clock
left male
OPTIONS
options (or just use pwm pins)
digital input
serial data
for oled, etc. option
for inmp441 mic, etc.
boot button

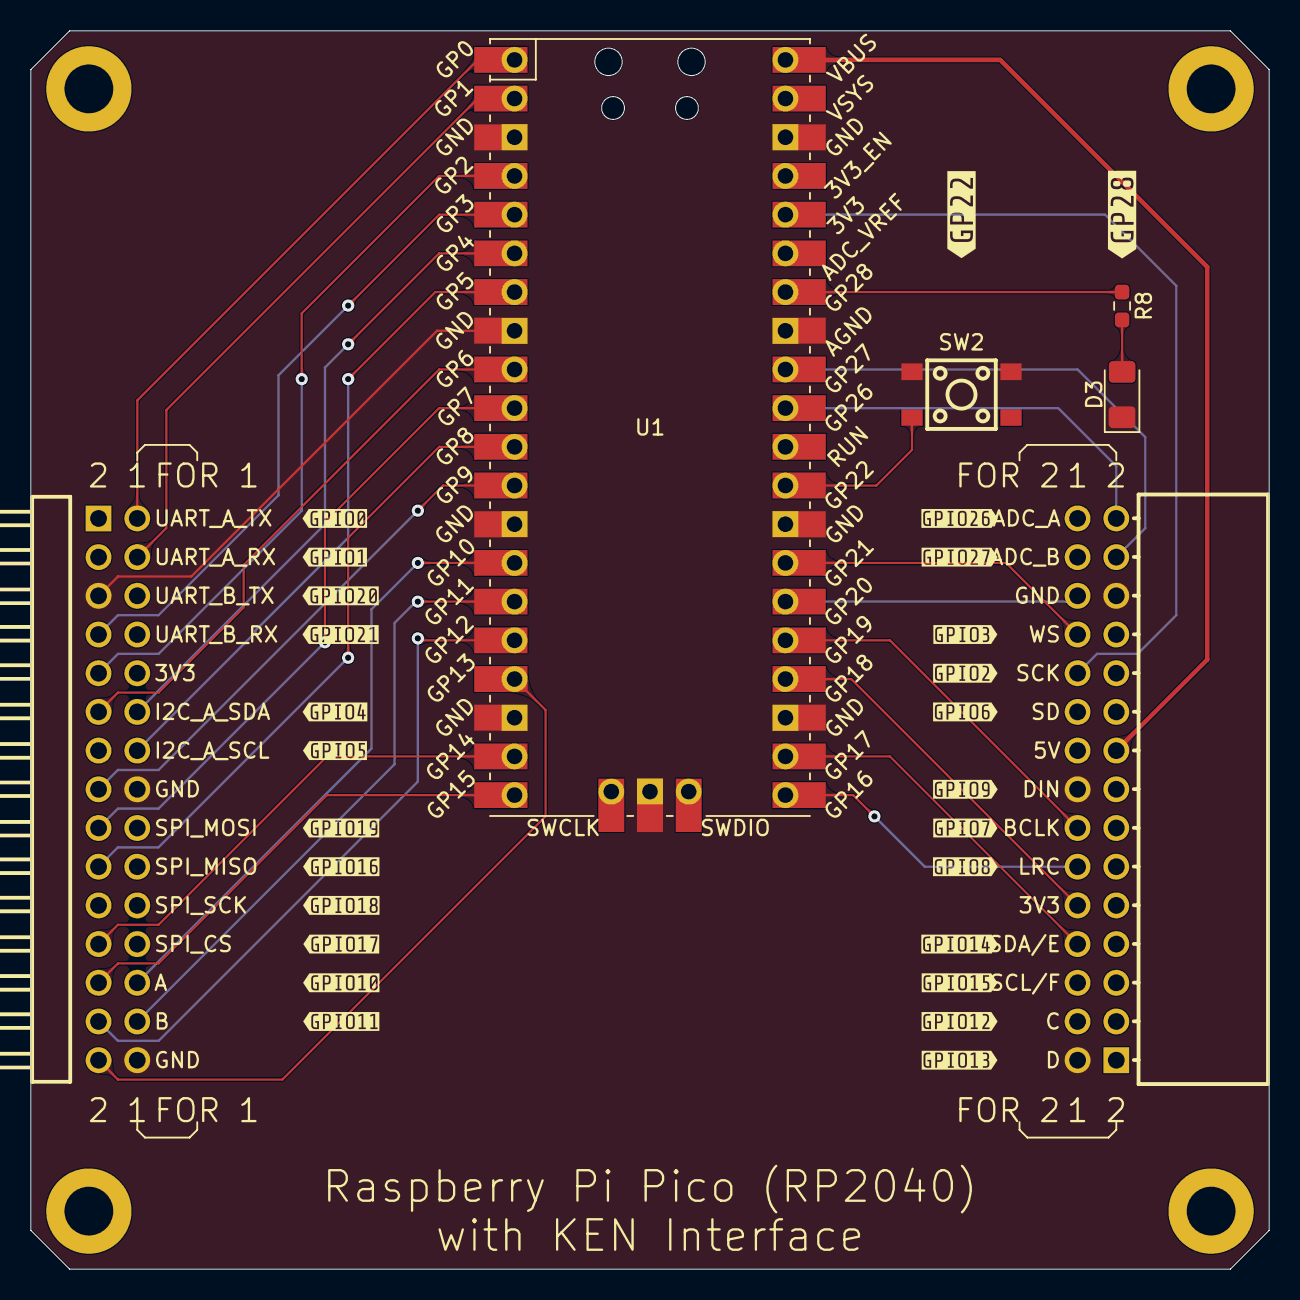
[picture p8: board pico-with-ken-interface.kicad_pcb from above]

Board: 4 copper layers, 81.3 x 81.3 mm, 36 parts (0 on the bottom side), 30 nets.

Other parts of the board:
kibuzzard-69ABCB94: G***; kibuzzard-69ABCB94
kibuzzard-69ABCBB2: G***; kibuzzard-69ABCBB2
kibuzzard-69B2BBD5: G***; kibuzzard-69B2BBD5
kibuzzard-69B2BBE8: G***; kibuzzard-69B2BBE8
kibuzzard-69B2BC4D: G***; kibuzzard-69B2BC4D
kibuzzard-69B2BC5B: G***; kibuzzard-69B2BC5B
kibuzzard-69B2BC8C: G***; kibuzzard-69B2BC8C
kibuzzard-69B2BC9C: G***; kibuzzard-69B2BC9C
kibuzzard-69B2BC53: G***; kibuzzard-69B2BC53
kibuzzard-69B2BC62: G***; kibuzzard-69B2BC62
kibuzzard-69B2BC71: G***; kibuzzard-69B2BC71
kibuzzard-69B2BCA8: G***; kibuzzard-69B2BCA8
kibuzzard-69B2BCB2: G***; kibuzzard-69B2BCB2
kibuzzard-69B2BCDF: G***; kibuzzard-69B2BCDF
kibuzzard-69B2BD0A: G***; kibuzzard-69B2BD0A
kibuzzard-69B2BD8D: G***; kibuzzard-69B2BD8D
kibuzzard-69B2BD9D: G***; kibuzzard-69B2BD9D
kibuzzard-69B2BD17: G***; kibuzzard-69B2BD17
kibuzzard-69B2BD42: G***; kibuzzard-69B2BD42
kibuzzard-69B2BD56: G***; kibuzzard-69B2BD56
kibuzzard-69B2BD62: G***; kibuzzard-69B2BD62
kibuzzard-69B2BD76: G***; kibuzzard-69B2BD76
kibuzzard-69B2BD80: G***; kibuzzard-69B2BD80
kibuzzard-69B2BDB2: G***; kibuzzard-69B2BDB2
kibuzzard-69B2BDBA: G***; kibuzzard-69B2BDBA
kibuzzard-69B2BDC4: G***; kibuzzard-69B2BDC4

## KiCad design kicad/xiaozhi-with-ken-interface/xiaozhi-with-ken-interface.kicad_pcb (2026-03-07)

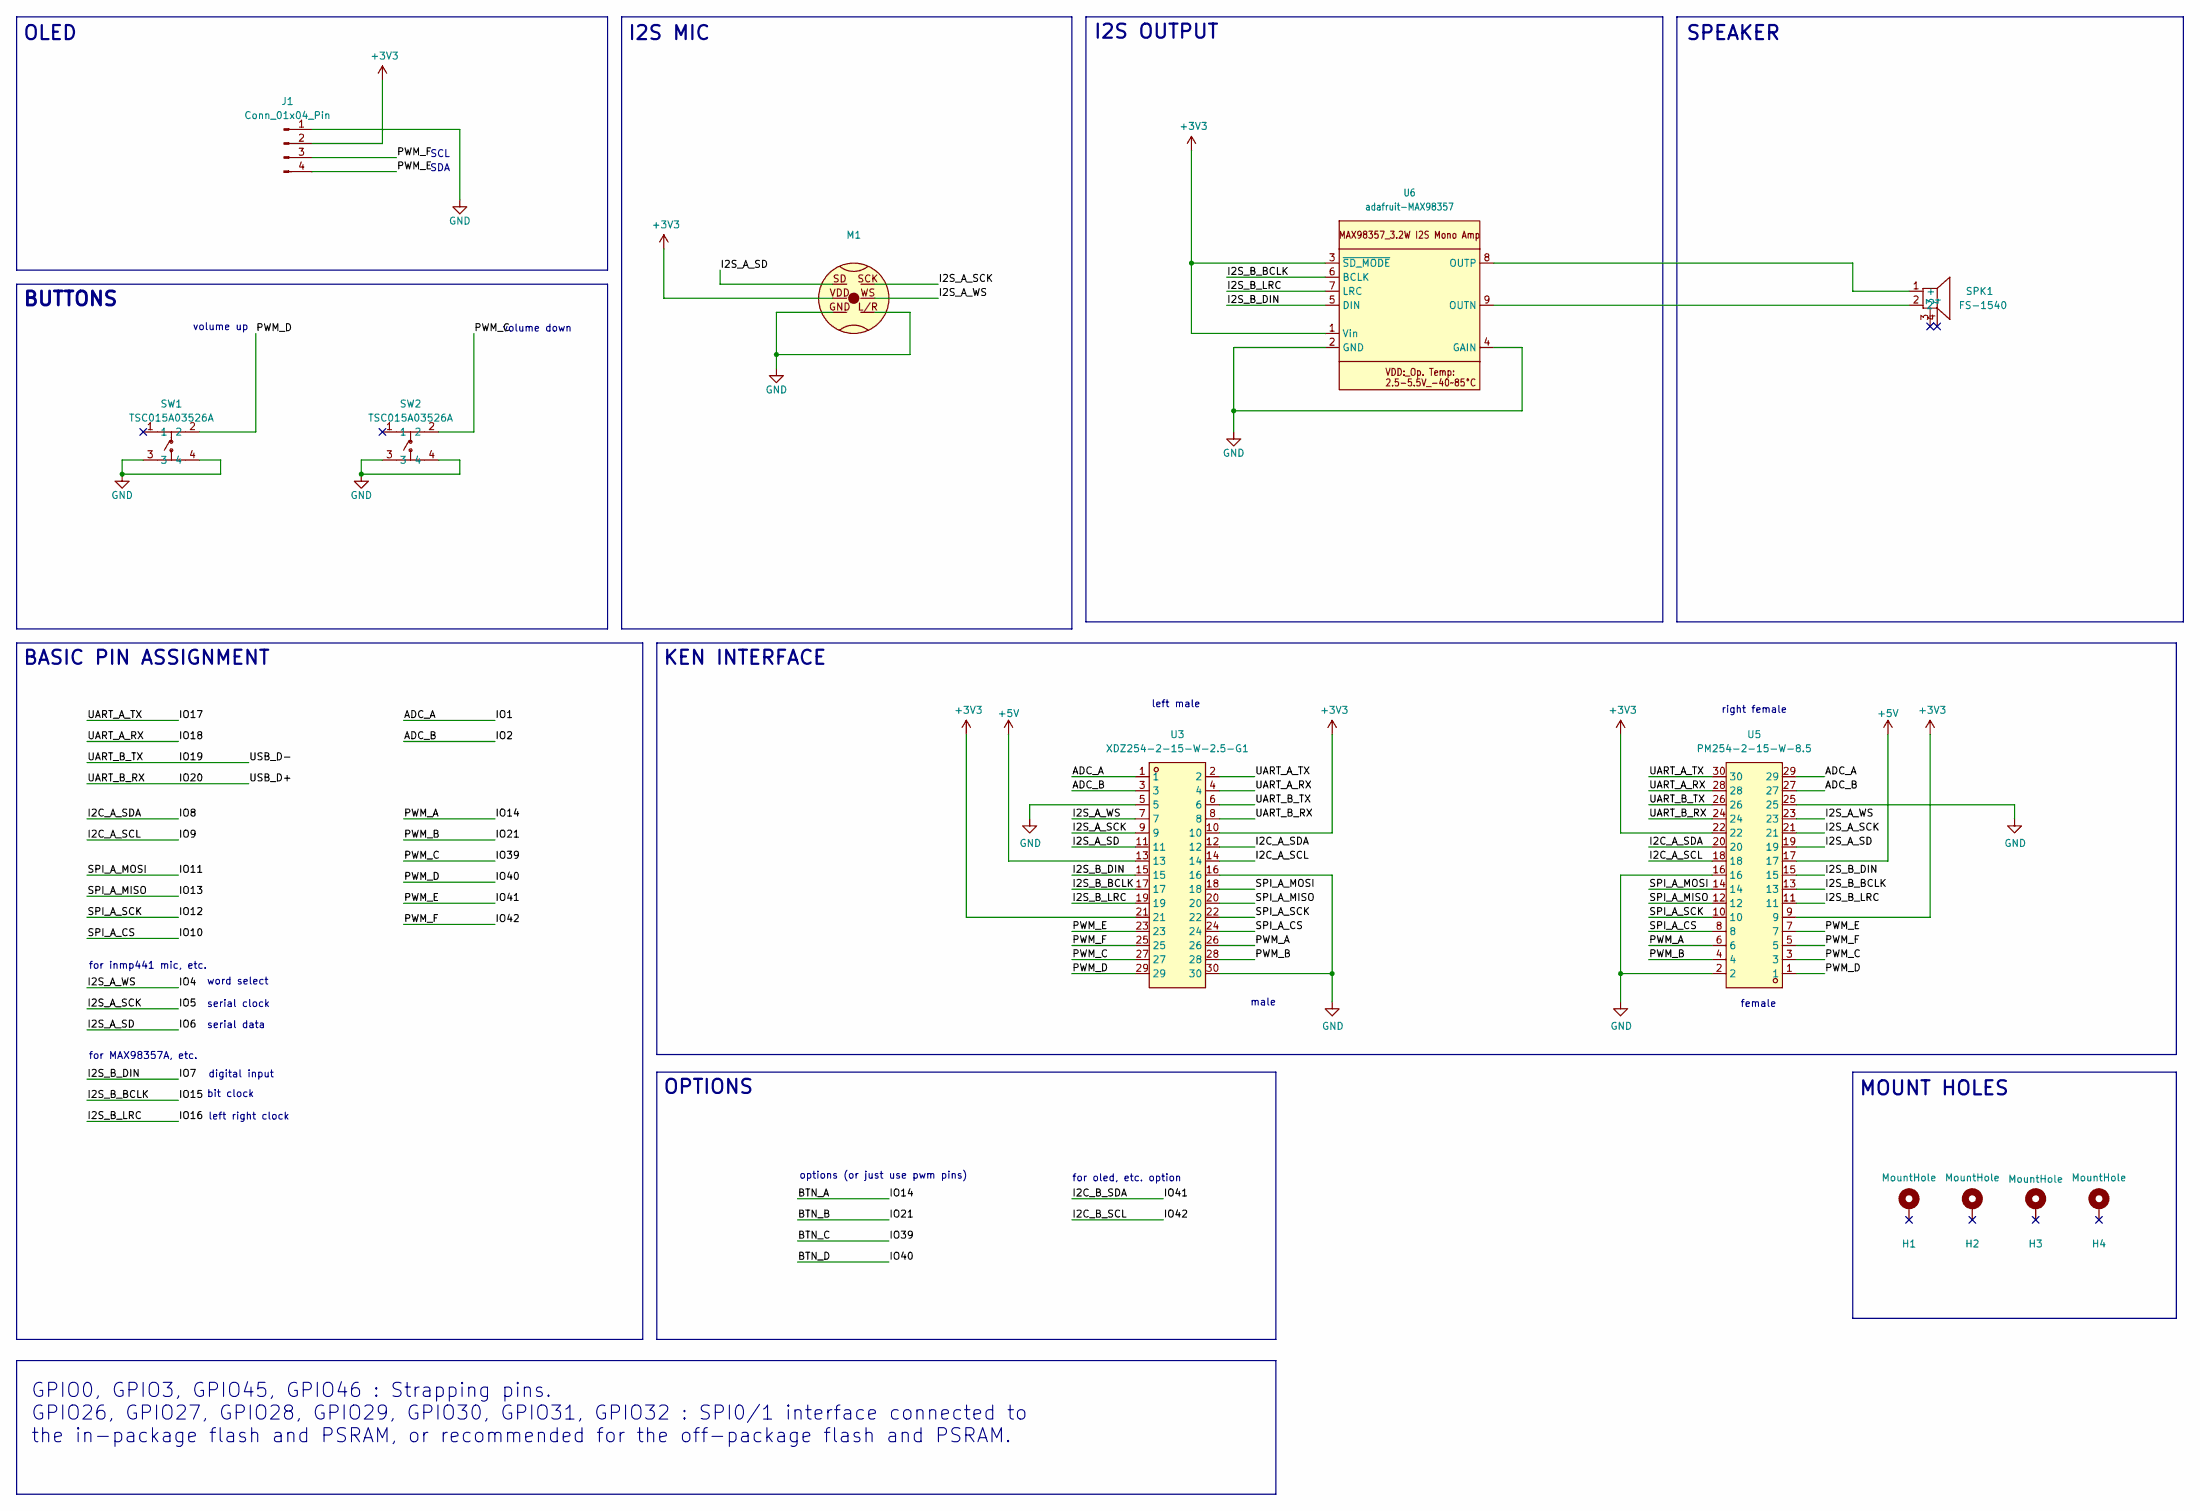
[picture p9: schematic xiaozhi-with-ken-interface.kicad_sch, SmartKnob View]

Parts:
H1, H2, H3, H4: MountHole; MountingHole_3.2mm_M3_DIN965_Pad; LCSC C2911210 or C2911532 (screw), C2961595 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
J1: Conn_01x04_Pin; SSD1306-0.91-OLED-4pin-128x32
M1: INMP441_OMNIDIRECTIONAL_MICROPHONE_MODULE
SPK1: FS-1540; BUZ-SMD_5P-L15.0-W15.0-P13.7-BL; LCSC Part C482341
SW1, SW2: TSC015A03526A; SW-SMD_4P-L4.5-W4.5-P3.00-LS6.8; LCSC Part C2888900
U3: XDZ254-2-15-W-2.5-G1; HDR-TH_30P-P2.54-H-M-R2-C15-S2.54-N; LCSC Part C18905913
U5: PM254-2-15-W-8.5; HDR-TH_30P-P2.54-H-F-R2-C15-W8.5; LCSC Part C2897435
U6: adafruit-MAX98357

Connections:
+3V3: J1.2, M1.VDD, U3.10, U3.21, U5.9, U5.22, U6.1 (Vin), U6.3 (~SD_MODE)
+5V: U3.13, U5.17
/ADC_A: U3.1, U5.29
/ADC_B: U3.3, U5.27
/BTN_A: U3.26, U5.6
/BTN_B: U3.28, U5.4
/BTN_C: SW2.2, U3.27, U5.3
/BTN_D: SW1.2, U3.29, U5.1
/I2C_A_SCL: U3.14, U5.18
/I2C_A_SDA: U3.12, U5.20
/I2C_B_SCL: J1.3, U3.25, U5.5
/I2C_B_SDA: J1.4, U3.23, U5.7
/I2S_A_SCK: M1.SCK, U3.9, U5.21
/I2S_A_SD: M1.SD, U3.11, U5.19
/I2S_A_WS: M1.WS, U3.7, U5.23
/I2S_B_BCLK: U3.17, U5.13, U6.6 (BCLK)
/I2S_B_DIN: U3.15, U5.15, U6.5 (DIN)
/I2S_B_LRC: U3.19, U5.11, U6.7 (LRC)
/IO10: U3.24, U5.8
/IO11: U3.18, U5.14
/IO12: U3.22, U5.10
/IO13: U3.20, U5.12
/IO17: U3.2, U5.30
/IO18: U3.4, U5.28
/IO19: U3.6, U5.26
/IO20: U3.8, U5.24
GND: J1.1, M1.GND, M1.L/R, SW1.3, SW1.4, SW2.3, SW2.4, U3.5, U3.16, U3.30, U5.2, U5.16, U5.25, U6.2 (GND), U6.4 (GAIN)
unnamed: SPK1.1 (+), U6.8 (OUTP)
unnamed: SPK1.2, U6.9 (OUTN)

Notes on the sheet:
OLED
for MAX98357A, etc.
KEN INTERFACE
GPIO0, GPIO3, GPIO45, GPIO46 : Strapping pins. GPIO26, GPIO27, GPIO28, GPIO29, GPIO30, GPIO31, GPIO32 : SPI0/1 interface connected to the in-package flash and PSRAM, or recommended for the off-package flash and PSRAM.
MOUNT HOLES
right female
SDA
female
word select
BASIC PIN ASSIGNMENT
male
serial clock
volume down
SPEAKER
left right clock
bit clock
left male
I2S MIC
OPTIONS
BUTTONS
options (or just use pwm pins)
volume up
SCL
digital input
serial data
I2S OUTPUT
for oled, etc. option
for inmp441 mic, etc.

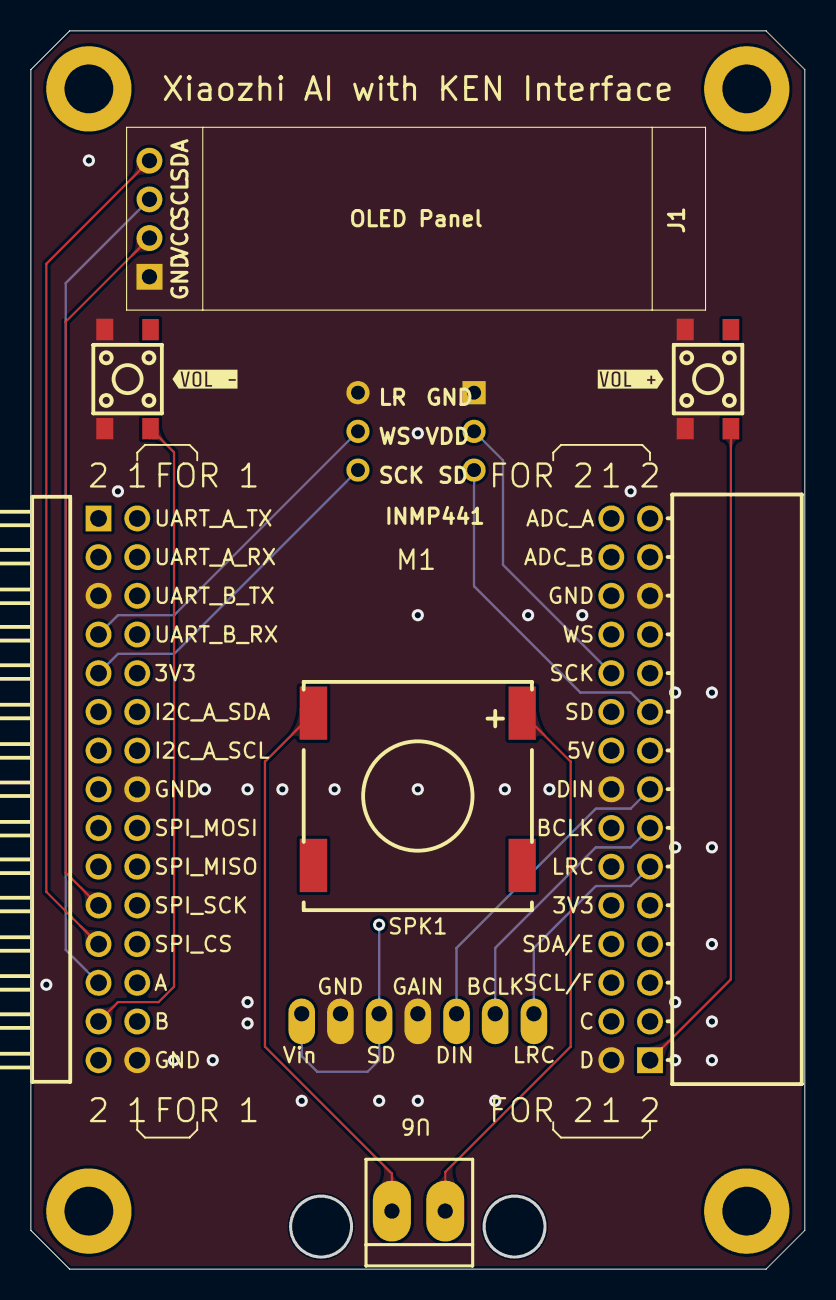
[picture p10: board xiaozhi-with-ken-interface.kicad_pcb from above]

Board: 4 copper layers, 50.8 x 81.3 mm, 14 parts (0 on the bottom side), 29 nets.

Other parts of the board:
kibuzzard-69756C5B: G***; kibuzzard-69756C5B
kibuzzard-69756C68: G***; kibuzzard-69756C68

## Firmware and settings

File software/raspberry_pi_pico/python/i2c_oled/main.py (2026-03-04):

import machine
import time
import math

# -------------------------
# I2C setup (SoftI2C)
# -------------------------
i2c = machine.SoftI2C(sda=machine.Pin(14), scl=machine.Pin(15), freq=400000)
ADDR = 0x3C
W, H = 128, 32

# -------------------------
# Low-level I2C functions
# -------------------------
def cmd(c):
    i2c.writeto(ADDR, bytes([0x80, c]))

_FLUSH_HDR = bytes([0x80,0x21, 0x80,0x00, 0x80,0x7F,
                    0x80,0x22, 0x80,0x00, 0x80,0x03])

def flush(buf):
    i2c.writeto(ADDR, _FLUSH_HDR)
    i2c.writeto(ADDR, b'\x40' + buf)

# -------------------------
# Display init
# -------------------------
for c in [0xAE, 0x20, 0x00, 0x40, 0xA1, 0xA8, 0x1F,
          0xC8, 0xD3, 0x00, 0xDA, 0x02, 0xD5, 0x80,
          0xD9, 0xF1, 0xDB, 0x30, 0x81, 0xFF,
          0xA4, 0xA6, 0x8D, 0x14, 0xAF]:
    cmd(c)

# -------------------------
# Framebuffer
# -------------------------
buf = bytearray(W * 4)  # 128 cols x 4 pages

def clear():
    buf[:] = bytes(W * 4)

def set_pixel(x, y, on=1):
    if 0 <= x < W and 0 <= y < H:
        idx = (y // 8) * W + x
        if on:
            buf[idx] |= (1 << (y % 8))
        else:
            buf[idx] &= ~(1 << (y % 8))

def draw_rect(x, y, w, h):
    for i in range(w):
        set_pixel(x + i, y)
        set_pixel(x + i, y + h - 1)
    for i in range(h):
        set_pixel(x, y + i)
        set_pixel(x + w - 1, y + i)

def fill_rect(x, y, w, h):
    # Compute page masks and write directly to buf
    for j in range(y, y + h):
        if 0 <= j < H:
            page = j // 8
            bit  = 1 << (j % 8)
            base = page * W
            for i in range(x, x + w):
                if 0 <= i < W:
                    buf[base + i] |= bit

# -------------------------
# 5x8 Font (A-Z, 0-9, symbols)
# -------------------------
FONT = {
    ' ': [0x00,0x00,0x00,0x00,0x00],
    '!': [0x00,0x00,0x5F,0x00,0x00],
    ',': [0x00,0x05,0x06,0x00,0x00],
    '.': [0x00,0x03,0x03,0x00,0x00],
    ':': [0x00,0x36,0x36,0x00,0x00],
    '-': [0x08,0x08,0x08,0x08,0x08],
    '0': [0x3E,0x51,0x49,0x45,0x3E],
    '1': [0x00,0x42,0x7F,0x40,0x00],
    '2': [0x42,0x61,0x51,0x49,0x46],
    '3': [0x21,0x41,0x45,0x4B,0x31],
    '4': [0x18,0x14,0x12,0x7F,0x10],
    '5': [0x27,0x45,0x45,0x45,0x39],
    '6': [0x3C,0x4A,0x49,0x49,0x30],
    '7': [0x01,0x71,0x09,0x05,0x03],
    '8': [0x36,0x49,0x49,0x49,0x36],
    '9': [0x06,0x49,0x49,0x29,0x1E],
    'A': [0x7E,0x11,0x11,0x11,0x7E],
    'B': [0x7F,0x49,0x49,0x49,0x36],
    'C': [0x3E,0x41,0x41,0x41,0x22],
    'D': [0x7F,0x41,0x41,0x22,0x1C],
    'E': [0x7F,0x49,0x49,0x49,0x41],
    'F': [0x7F,0x09,0x09,0x09,0x01],
    'G': [0x3E,0x41,0x49,0x49,0x7A],
    'H': [0x7F,0x08,0x08,0x08,0x7F],
    'I': [0x00,0x41,0x7F,0x41,0x00],
    'J': [0x20,0x40,0x41,0x3F,0x01],
    'K': [0x7F,0x08,0x14,0x22,0x41],
    'L': [0x7F,0x40,0x40,0x40,0x40],
    'M': [0x7F,0x02,0x0C,0x02,0x7F],
    'N': [0x7F,0x04,0x08,0x10,0x7F],
    'O': [0x3E,0x41,0x41,0x41,0x3E],
    'P': [0x7F,0x09,0x09,0x09,0x06],
    'Q': [0x3E,0x41,0x51,0x21,0x5E],
    'R': [0x7F,0x09,0x19,0x29,0x46],
    'S': [0x46,0x49,0x49,0x49,0x31],
    'T': [0x01,0x01,0x7F,0x01,0x01],
    'U': [0x3F,0x40,0x40,0x40,0x3F],
    'V': [0x1F,0x20,0x40,0x20,0x1F],
    'W': [0x3F,0x40,0x38,0x40,0x3F],
    'X': [0x63,0x14,0x08,0x14,0x63],
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
}

def draw_char(x, y, ch):
    glyph = FONT.get(ch.upper(), FONT[' '])
    page = y // 8
    shift = y % 8
    for col, byte in enumerate(glyph):
        cx = x + col
        if 0 <= cx < W:
            if shift == 0:
                buf[page * W + cx] |= byte
            else:
                buf[page * W + cx]       |= (byte << shift) & 0xFF
                if page + 1 < 4:
                    buf[(page+1) * W + cx] |= byte >> (8 - shift)

def draw_text(x, y, text):
    cx = x
    for ch in text:
        draw_char(cx, y, ch)
        cx += 6

def center_text(text, y):
    x = (W - len(text) * 6) // 2
    draw_text(max(x, 0), y, text)

# Precompute sine LUT (256 steps, one full cycle)
_SIN_LUT = [int((H/2) + (H/2 - 2) * math.sin(i * 2 * math.pi / 256)) for i in range(256)]

# -------------------------
# Demo 1: Splash screen
# -------------------------
def demo_splash():
    clear()
    center_text("RASPBERRY PI", 2)
    center_text("PICO  DEMO", 18)
    flush(buf)
    time.sleep(2)

# -------------------------
# Demo 2: Scrolling text
# -------------------------
def demo_scroll():
    message = "  HELLO  MICROPYTHON  "
    msg_w = len(message) * 6
    for offset in range(msg_w):
        clear()
        draw_text(-offset, 12, message)
        draw_text(-offset + msg_w, 12, message)
        flush(buf)

# -------------------------
# Demo 3: Counter
# -------------------------
def demo_counter():
    for i in range(20):
        clear()
        center_text("COUNTER", 2)
        center_text("{:04d}".format(i), 18)
        flush(buf)
        time.sleep(0.12)

# -------------------------
# Demo 4: Progress bar
# -------------------------
def demo_progress():
    for i in range(W + 1):
        clear()
        center_text("LOADING", 2)
        draw_rect(0, 20, W, 11)
        fill_rect(2, 22, i * (W - 4) // W, 7)
        flush(buf)
        time.sleep(0.005)
    time.sleep(0.5)

# -------------------------
# Demo 5: Sine wave
# -------------------------
def demo_sine():
    for frame in range(100):
        clear()
        for x in range(W):
            y = _SIN_LUT[(x * 2 + frame * 8) & 0xFF]
            set_pixel(x, max(0, min(H - 1, y)))
        flush(buf)
        time.sleep(0.03)

# -------------------------
# Demo 6: Bouncing ball
# -------------------------
def demo_bounce():
    bx, by = W // 2, H // 2
    vx, vy = 3, 2
    r = 4
    for _ in range(100):
        clear()
        x, y, p = r, 0, 1 - r
        while x >= y:
            for dx, dy in [(x,y),(-x,y),(x,-y),(-x,-y),(y,x),(-y,x),(y,-x),(-y,-x)]:
                set_pixel(bx + dx, by + dy)
            y += 1
            p = p + 2*y+1 if p <= 0 else p + 2*(y-x)+1
            if p > 0: x -= 1
        bx += vx; by += vy
        if bx - r <= 0 or bx + r >= W - 1: vx = -vx
        if by - r <= 0 or by + r >= H - 1: vy = -vy
        flush(buf)
        time.sleep(0.03)

# -------------------------
# Main loop
# -------------------------
demos = [
    ("Splash",   demo_splash),
    ("Scroll",   demo_scroll),
    ("Counter",  demo_counter),
    ("Progress", demo_progress),
    ("Sine",     demo_sine),
    ("Bounce",   demo_bounce),
]

print("OLED demo started")
while True:
    for name, demo in demos:
        print("Running:", name)
        demo()
        time.sleep(0.5)

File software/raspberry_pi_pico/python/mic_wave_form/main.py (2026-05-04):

import machine
import time
import struct

# -------------------------
# OLED: SoftI2C (SDA=GP14, SCL=GP15)
# -------------------------
i2c = machine.SoftI2C(sda=machine.Pin(14), scl=machine.Pin(15), freq=400000)
ADDR = 0x3C
W, H = 128, 32

def cmd(c):
    i2c.writeto(ADDR, bytes([0x80, c]))

# All 6 address-setup commands batched into one I2C transaction
_FLUSH_HDR = bytes([0x80,0x21, 0x80,0x00, 0x80,0x7F,
                    0x80,0x22, 0x80,0x00, 0x80,0x03])

def flush(buf):
    i2c.writeto(ADDR, _FLUSH_HDR)
    i2c.writeto(ADDR, b'\x40' + buf)

# Display init
for c in [0xAE, 0x20, 0x00, 0x40, 0xA1, 0xA8, 0x1F,
          0xC8, 0xD3, 0x00, 0xDA, 0x02, 0xD5, 0x80,
          0xD9, 0xF1, 0xDB, 0x30, 0x81, 0xFF,
          0xA4, 0xA6, 0x8D, 0x14, 0xAF]:
    cmd(c)

# Framebuffer: 4 pages x 128 cols
buf = bytearray(W * 4)

# Precomputed lookup tables for set_pixel speed
_PAGE = bytes([y >> 3  for y in range(H)])   # page index for each y
_BIT  = bytes([1 << (y & 7) for y in range(H)])  # bitmask for each y

# -------------------------
# I2S Microphone: INMP441
# SCK=GP4, WS=GP5, SD=GP6
# -------------------------
SAMPLE_RATE = 16000
NUM_SAMPLES = W          # one sample per display column

audio_in = bytearray(NUM_SAMPLES * 4)   # 32-bit per sample

i2s = machine.I2S(
    0,
    sck=machine.Pin(2),   # SCK = GP2
    ws=machine.Pin(3),    # WS  = GP3
    sd=machine.Pin(6),    # SD  = GP6
    mode=machine.I2S.RX,
    bits=32,
    format=machine.I2S.MONO,
    rate=SAMPLE_RATE,
    ibuf=NUM_SAMPLES * 4 * 8
)

# -------------------------
# AGC (Auto Gain Control) settings
# -------------------------
NOISE_GATE   = 800     # Ignore signals below this (cuts AC background hum)
AGC_MAX_AMP  = (H // 2 - 2)  # Max display amplitude in pixels (= 14px)
CENTER_Y     = H // 2        # = 16
agc_peak     = 1000    # Running peak estimate (starts small, adapts quickly)
AGC_ATTACK   = 0.3     # How fast gain reduces when signal is loud  (0~1)
AGC_RELEASE  = 0.02    # How fast gain recovers in silence          (0~1)

# -------------------------
# Draw a vertical line in column x from y0 to y1 (inclusive)
# Operates directly on buf pages — avoids per-pixel overhead
# -------------------------
def draw_vline(x, y0, y1):
    if y0 > y1:
        y0, y1 = y1, y0
    y0 = max(0, y0)
    y1 = min(H - 1, y1)
    p0, p1 = y0 >> 3, y1 >> 3
    if p0 == p1:
        # Both endpoints in the same page: single write
        mask = 0
        for b in range(y0 & 7, (y1 & 7) + 1):
            mask |= 1 << b
        buf[p0 * W + x] |= mask
    else:
        # Bottom of first page
        mask = 0
        for b in range(y0 & 7, 8):
            mask |= 1 << b
        buf[p0 * W + x] |= mask
        # Full middle pages
        for p in range(p0 + 1, p1):
            buf[p * W + x] = 0xFF
        # Top of last page
        mask = 0
        for b in range(0, (y1 & 7) + 1):
            mask |= 1 << b
        buf[p1 * W + x] |= mask

# -------------------------
# Main loop
# -------------------------
print("Waveform display started")
prev_y = CENTER_Y

while True:
    # --- Capture audio (blocking read, fills exactly NUM_SAMPLES) ---
    i2s.readinto(audio_in)

    # --- Clear framebuffer ---
    buf[:] = bytes(W * 4)

    # --- Render waveform ---
    # Draw center line (dashed every 4px for reference)
    for x in range(0, W, 4):
        buf[_PAGE[CENTER_Y] * W + x] |= _BIT[CENTER_Y]

    # --- AGC: find peak amplitude in this frame ---
    frame_peak = 0
    for x in range(W):
        idx = x << 2
        raw = (audio_in[idx+3] << 24 | audio_in[idx+2] << 16 |
               audio_in[idx+1] <<  8 | audio_in[idx])
        if raw >= 0x80000000:
            raw -= 0x100000000
        sample24 = raw >> 8
        amp = sample24 if sample24 >= 0 else -sample24
        if amp > frame_peak:
            frame_peak = amp

    # Noise gate: if frame is silent, show flat line
    if frame_peak < NOISE_GATE:
        buf[:] = bytes(W * 4)
        for x in range(0, W, 4):
            buf[_PAGE[CENTER_Y] * W + x] |= _BIT[CENTER_Y]
        flush(buf)
        prev_y = CENTER_Y
        continue

    # Update running peak with attack/release
    if frame_peak > agc_peak:
        agc_peak = int(agc_peak * (1 - AGC_ATTACK)  + frame_peak * AGC_ATTACK)
    else:
        agc_peak = int(agc_peak * (1 - AGC_RELEASE) + frame_peak * AGC_RELEASE)
    agc_peak = max(agc_peak, NOISE_GATE)

    # --- Render waveform with AGC scale ---
    for x in range(W):
        idx = x << 2
        raw = (audio_in[idx+3] << 24 | audio_in[idx+2] << 16 |
               audio_in[idx+1] <<  8 | audio_in[idx])
        if raw >= 0x80000000:
            raw -= 0x100000000
        sample24 = raw >> 8
        y = CENTER_Y - int(sample24 * AGC_MAX_AMP / agc_peak)
        y = max(0, min(H - 1, y))
        draw_vline(x, prev_y, y)
        prev_y = y

    # --- Push buffer to OLED in 2 I2C transactions ---
    flush(buf)

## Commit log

2026-01-20 get parts ready, first routing
    [esp32-s3-with-ken-interface.kicad_pcb, esp32-s3-with-ken-interface.kicad_sch]
2026-01-20 fix left pin header pin assignment
    [esp32-s3-with-ken-interface.kicad_pcb, esp32-s3-with-ken-interface.kicad_sch]
2026-01-20 adjust traces
    [esp32-s3-with-ken-interface.kicad_pcb]
2026-01-21 add pin label, adjust routing, add PWM pins
    [esp32-s3-with-ken-interface.kicad_pcb, esp32-s3-with-ken-interface.kicad_sch]
2026-01-22 add protect diode, improve trace routing, add vias, add user button and user led, improve schematic, add texts
    [esp32-s3-with-ken-interface.kicad_pcb, esp32-s3-with-ken-interface.kicad_sch]
2026-01-23 improve schematic and trace routing, improve silk text, etc
    [esp32-s3-with-ken-interface.kicad_pcb, esp32-s3-with-ken-interface.kicad_sch]
2026-01-23 a little update for layouts and routing
    [esp32-s3-with-ken-interface.kicad_pcb]
2026-01-23 rename ADC_1 to ADC_A, ADC_2 to ADC_B,also update the silk text
    [esp32-s3-with-ken-interface.kicad_pcb, esp32-s3-with-ken-interface.kicad_sch]
2026-01-23 update schematic
    [esp32-s3-with-ken-interface.kicad_pcb, esp32-s3-with-ken-interface.kicad_sch]
2026-01-24 add KiCad project for xiaozhi AI with KEN interface
    [esp32-s3-with-ken-interface.kicad_pcb, esp32-s3-with-ken-interface.kicad_sch, xiaozhi-with-ken-interface.kicad_pcb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]
2026-01-24 update s3 model for oled display
    [xiaozhi-with-ken-interface.kicad_pcb]
2026-01-25 improve routing for ESP32-S3 board
    [esp32-s3-with-ken-interface.kicad_pcb]
2026-01-25 add boot button to ESP32-S3 board, add speaker to xiaozhi, improve xiaozhi board schematic and routing.
    [esp32-s3-with-ken-interface.kicad_pcb, esp32-s3-with-ken-interface.kicad_sch, xiaozhi-with-ken-interface.kicad_pcb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]
2026-01-25 small update
    [esp32-s3-with-ken-interface.kicad_pcb, xiaozhi-with-ken-interface.kicad_pcb]
2026-01-25 adjust 3d model position
    [xiaozhi-with-ken-interface.kicad_pcb]
2026-01-25 final adjust, send to pcb maker
    [esp32-s3-with-ken-interface-B_Cu.gbr, esp32-s3-with-ken-interface-B_Mask.gbr, esp32-s3-with-ken-interface-B_Paste.gbr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]
2026-02-02 add template project
    [template-B_Cu.gbr, template-B_Mask.gbr, template-B_Paste.gbr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]
2026-02-02 add text
    [template.kicad_pcb]
2026-02-02 add Raspberry Pi Pico with KEN interface, WIP
    [pico-with-ken-interface-B_Cu.gbr, pico-with-ken-interface-B_Mask.gbr, pico-with-ken-interface-B_Paste.gbr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]
2026-02-02 edited labels for template project PCB
    [template.kicad_pcb]
2026-02-03 bring back button symbol and foot print, did some routing.
    [pico-with-ken-interface.kicad_pcb, pico-with-ken-interface.kicad_sch]
2026-02-03 first routing for pico
    [pico-with-ken-interface.kicad_pcb, pico-with-ken-interface.kicad_sch]
2026-02-03 add button and LED
    [pico-with-ken-interface.kicad_pcb, pico-with-ken-interface.kicad_sch]
2026-02-04 finalize pin assignment for pico board
    [pico-with-ken-interface.kicad_pcb, pico-with-ken-interface.kicad_sch]
2026-02-04 trace adjust
    [pico-with-ken-interface.kicad_pcb]
2026-02-05 add display board with ken interface
    [display-with-ken-interface.kicad_pcb, display-with-ken-interface.kicad_sch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]
2026-02-11 ready to send pico board to manufacturing
    [pico-with-ken-interface-B_Cu.gbr, pico-with-ken-interface-B_Mask.gbr, pico-with-ken-interface-B_Paste.gbr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]
2026-02-19 add 3d models for display, adjust pin header placement
    [2.2 inch tft display .step, Display 1.69 ST7789V2.stp, display-with-ken-interface.kicad_pcb]
2026-02-23 fix text
    [display-with-ken-interface.kicad_pcb]
2026-02-24 display board is ready to send to pcb maker
    [display-with-ken-interface-B_Cu.gbr, display-with-ken-interface-B_Mask.gbr, display-with-ken-interface-B_Paste.gbr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]
2026-02-24 add teartrop
    [display-with-ken-interface-B_Cu.gbr, display-with-ken-interface-B_Mask.gbr, display-with-ken-interface-B_Paste.gbr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]
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2026-03-04 sda:14, scl:15 I2C oled display demo, and mic wave form demo
    [esp32-s3-with-ken-interface.kicad_sch]
2026-03-07 fix labels, update manufacture files
    [esp32-s3-with-ken-interface-B_Cu.gbr, esp32-s3-with-ken-interface-B_Mask.gbr, esp32-s3-with-ken-interface-B_Paste.gbr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]
2026-03-12 use 4,5 for default I2C pins
    [pico-with-ken-interface.kicad_pcb, pico-with-ken-interface.kicad_sch]
2026-03-12 add labels for pico pins
    [pico-with-ken-interface.kicad_pcb]
2026-03-15 adjust labels, send to pcb maker
    [pico-with-ken-interface-B_Cu.gbr, pico-with-ken-interface-B_Mask.gbr, pico-with-ken-interface-B_Paste.gbr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]
2026-03-19 add reset button
    [esp32-s3-with-ken-interface.kicad_pcb, esp32-s3-with-ken-interface.kicad_sch]
2026-03-26 update symbol
    [display-with-ken-interface.kicad_pcb, esp32-s3-with-ken-interface.kicad_pcb, esp32-s3-with-ken-interface.kicad_sch]
2026-03-27 save kicad file
    [pico-with-ken-interface.kicad_pcb]
2026-04-12 update pico 3d model size
    [pico-with-ken-interface.kicad_pcb]
2026-04-21 add project for renewed display board
    [2.2 inch tft display .step, Display 1.69 ST7789V2.stp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]
2026-04-22 new display board send to pcb maker
    [display-with-ken-interface-2-B_Cu.gbr, display-with-ken-interface-2-B_Mask.gbr, display-with-ken-interface-2-B_Paste.gbr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]
2026-04-27 add capacitor
    [esp32-s3-with-ken-interface.kicad_pcb, esp32-s3-with-ken-interface.kicad_sch]
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
